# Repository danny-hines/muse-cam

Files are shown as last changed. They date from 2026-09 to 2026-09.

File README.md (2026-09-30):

# Muse Cam

Muse Cam is a physical AI camera that captures a photograph, applies a playful Muse Image preset through Meta Model API, shows the result on the camera, and optionally publishes it to a public web roll.

This repository contains both sides of the project:

- `web/` — Next.js site and device API deployed to Vercel.
- `device-ui/` — touch-first React interface compiled into the Raspberry Pi package.
- `device/` — portable Python client and hardware profiles for Raspberry Pi.
- `hardware/` — physical build plan, working parts list, source CAD, and printable exports.
- `scripts/` — repeatable device installation tooling.
- `docs/` — API and deployment documentation.

## Current status

The web/API foundation is functional:

- Responsive per-event galleries that update live, a full-screen slideshow for event screens, an event-code home page, and individual photo pages.
- Individual, revocable device credentials plus a legacy single-token fallback.
- Event assignment and 30-minute, single-use device setup codes.
- Idempotent capture IDs.
- Generation, status, image download, share, and unshare endpoints.
- Thirty versioned image presets, plus per-event style lists and event-only styles.
- Mock image transformation for end-to-end development without a Meta key.
- Neon Postgres and private/public Vercel Blob adapters.
- A protected operator dashboard for registration, moderation, and deletion.
- Opt-in original-photo publishing with an accessible before/after control.
- Muse Spark captions for shared photos, written after publishing.
- In-memory development fallbacks and included demo frames.

The Raspberry Pi application includes Picamera2 capture, local SQLite queuing, offline retry, diagnostics, systemd startup, and desktop simulation. It has two interchangeable front ends: the proven native framebuffer app for SPI/HAT displays and a local Chromium interface for the 800×480 Waveshare DSI display. The browser never receives the device credential; it talks only to the camera service on localhost.

## Local development

Requirements: Node.js 20.9+ and pnpm 11.

```bash
cp web/.env.example web/.env.local
pnpm install
pnpm dev
```

Set a development `DEVICE_API_TOKEN` in `web/.env.local`. With `MODEL_PROVIDER=mock`, Neon and Blob are optional. Open [http://localhost:3000/demo](http://localhost:3000/demo) for the demo gallery and [http://localhost:3000/api/health](http://localhost:3000/api/health) for configuration status.

Useful commands:

```bash
pnpm typecheck
pnpm lint
pnpm test
pnpm build
pnpm --dir web token:hash
pnpm --dir web admin:credentials
```

## Deploying to Vercel

1. Import this repository into Vercel and select `web` as the project root.
2. Provision Neon Postgres from the Vercel Marketplace and connect it as `DATABASE_URL`.
3. Create two Vercel Blob stores: one **private** and one **public**.
4. Connect their tokens as `PRIVATE_BLOB_READ_WRITE_TOKEN` and `PUBLISHED_BLOB_READ_WRITE_TOKEN`.
5. Run `pnpm --dir web db:migrate` against the connected Neon database.
6. Generate operator credentials with `pnpm --dir web admin:credentials`, then add the two emitted environment variables to Vercel.
7. Keep the existing `DEVICE_API_TOKEN_SHA256` and `DEVICE_ID` during migration. New cameras can use individual credentials created at `/admin`.
8. Add `SITE_URL`. When enabling Muse Image, add `META_API_KEY`; the documented endpoint and `muse-image-1.0` model are built-in defaults. The same key lets `muse-spark-1.3` caption shared photos.
9. Set `MODEL_PROVIDER=mock` for the first deployment smoke test.
10. Switch to `MODEL_PROVIDER=meta` after adding the Meta API key and running a live image-edit smoke test.

Production device mutations intentionally refuse to run until the database, both Blob stores, device authentication, and selected model provider are configured.

## API smoke test from a workstation

Every photo belongs to an event, so first assign the camera to an event at `/admin`. Until then, uploads return a retryable `503` (`camera_unassigned`).

```bash
curl -X POST http://localhost:3000/api/device/generations \
  -H "Authorization: Bearer $MUSECAM_DEVICE_TOKEN" \
  -F "capture_id=test_$(date +%s)" \
  -F "preset_id=alien-visitor" \
  -F "image=@/absolute/path/to/photo.jpg"
```

See [docs/API.md](docs/API.md) for the complete flow.

## Raspberry Pi installation

The public installer supports the current Camera Module 3 / Pi 3B+ / DSI build and the alternate hardware profiles:

```bash
curl -fsSL https://raw.githubusercontent.com/danny-hines/muse-cam/main/scripts/install-device.sh \
  | sudo bash -s -- --profile pi3bplus-cam3-dsi43 --claim YOUR-SETUP-CODE
```

For the PiSugar 3 Plus, also complete [battery setup](docs/POWER.md) and set `MUSECAM_POWER_BACKEND=pisugar3`. Use `pi3bplus-imx415-tft35` for the SPI screen or `zero2-cam3-displayhat` for the Pi Zero 2 W version. See [docs/DEVICE.md](docs/DEVICE.md) for wiring, diagnostics, simulator usage, and hardware bring-up. See [docs/ADMIN.md](docs/ADMIN.md) for registration and moderation.

The [parts list](hardware/BOM.md), [illustrated build guide](hardware/BUILD.md), [GPIO wiring](hardware/WIRING.md), and [six enclosure STL files](hardware/stl/README.md) cover the Camera Module 3 / PiSugar 3 Plus build. The guide follows the September 16, 2026 assembly notes and includes ten [assembly photos](hardware/photos/README.md) plus four [completed-camera views](hardware/BUILD.md#completed-camera); print settings and a few measurements remain pending. The enclosed prototype processes photos over Wi-Fi and has working audio and battery reporting; Camera Module 3 autofocus remains unresolved in the [recorded hardware checks](docs/CAMERAS.md).

## Privacy defaults

- Uploaded source images are normalized and stripped of EXIF before storage.
- Originals and unshared results use a private Blob store.
- A result is copied to the public Blob store only after the share endpoint is called.
- Event galleries never expose the source photograph unless an operator explicitly enables originals for that photo or event.
- Hiding a photo deletes both public copies but retains private media; permanent deletion removes the database record and all stored media.

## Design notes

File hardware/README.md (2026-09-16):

# Build a Muse Cam

Print the six enclosure parts, gather the [parts list](BOM.md), and follow the
[assembly guide](BUILD.md). Keep the [wiring reference](WIRING.md) nearby while
connecting the amplifier and shutter.

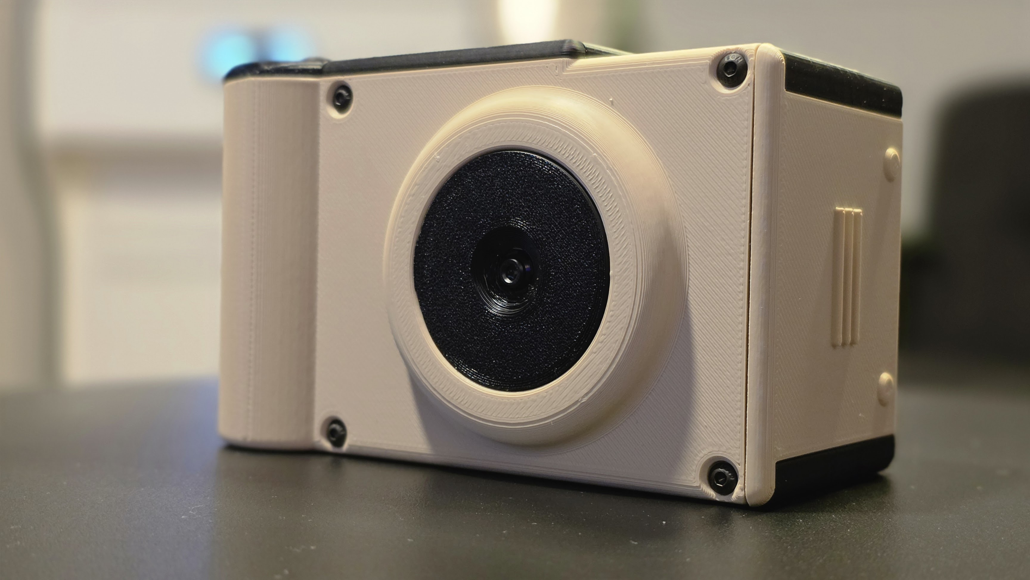
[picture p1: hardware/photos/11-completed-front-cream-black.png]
Completed Muse Cam with cream front and side panels, black housing, and a recessed camera lens


The completed camera. See [front, rear, and open-door views](BUILD.md#completed-camera)
in cream/black and orange/white.

## Current build

The September 16, 2026 instructions cover Danny's enclosure with:

- Raspberry Pi 3 Model B+.
- Raspberry Pi Camera Module 3 Standard.
- Waveshare 4.3-inch 800×480 DSI touchscreen.
- PiSugar 3 Plus and battery.
- MAX98357A I²S amplifier and 3 W speaker kit.
- A 10 mm momentary shutter switch and magnet-retained access doors.

Use software profile `pi3bplus-cam3-dsi43` with
`MUSECAM_POWER_BACKEND=pisugar3`. The shutter connects to physical pins **38 and
39**; physical pin **40** is reserved for amplifier DIN.

## Files

| Resource | Contents |
| --- | --- |
| [Parts list](BOM.md) | Purchase links, quantities, screws, cables, and supplies |
| [Build guide](BUILD.md) | Printing, assembly, software setup, and final checks |
| [Build photos](photos/README.md) | Ten assembly photos and four completed-camera views |
| [Wiring reference](WIRING.md) | Physical pin numbers, BCM GPIO numbers, and audio setup |
| [STL files](stl/README.md) | Six original exports, dimensions, and SHA-256 checksums |
| [Source CAD](cad/README.md) | Location for editable models; source files are still pending |
| [Device setup](../docs/DEVICE.md) | OS installation, diagnostics, and operation |
| [Battery setup](../docs/POWER.md) | PiSugar 3 Plus telemetry and power-manager configuration |

## Build status

An enclosed prototype has processed photos over Wi-Fi, and its amplifier/speaker
has played clean audio. Application sound cues are implemented. Camera Module 3
preview/capture were checked on September 12, and PiSugar 3 Plus battery reporting
on September 13; see [camera results](../docs/CAMERAS.md) and
[power results](../docs/POWER.md).

The guide includes **ten assembly photos and four completed-camera views**
showing the four-magnet layout, door stops, display, Pi/PiSugar stack, lens mount,
speaker placement, and side-door access to USB and Ethernet. The six
supplied STLs are unchanged, with file-integrity and dimension checks. Print
settings, exact screw-head dimensions and M2.5 lengths, cable lengths, and some
connector details still need to be recorded. Camera Module 3 autofocus remains
unresolved in the existing test record, so check lens clearance and near/far
focus before closing the housing.

The assembly guide lists the remaining measurements and checks. Other
software-supported cameras and displays are listed in
[DEVICE.md](../docs/DEVICE.md); their mechanical fit is not established by this
STL set.

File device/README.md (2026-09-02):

# Muse Cam device application

The device package contains the Raspberry Pi camera service, native UI, and production API client. It includes:

- Picamera2 and desktop-simulator camera adapters.
- Direct RGB565 framebuffer and Pimoroni Display HAT Mini outputs.
- Touch, integrated HAT button, GPIO shutter, and long-press power input.
- A responsive Pygame UI for preset selection, capture, processing, review, and sharing.
- A local HTTP/SSE/MJPEG service for the touch-first Chromium UI, with credentials isolated from the browser.
- SQLite persistence and offline retry using idempotent capture IDs.
- PiSugar 2 battery telemetry.
- Hardware diagnostics and systemd startup.

See [`../docs/DEVICE.md`](../docs/DEVICE.md) for installation, wiring, simulation, and hardware bring-up.

The API-only commands remain useful during diagnosis:

```bash
musecam health
musecam presets
musecam claim XXXX-XXXX-XXXX-XXXX
musecam submit /absolute/path/photo.jpg --preset kid-drawing --share
musecam doctor
```

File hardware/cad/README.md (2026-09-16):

# Source CAD

Store editable enclosure and bracket models here. Prefer a format that preserves the
design history; include a neutral STEP export when the authoring tool supports it.

Each CAD release should document:

- Hardware revision and compatible device profile.
- Authoring application and version.
- Units and critical tolerances.
- Purchased-part models used as references and their licenses.
- Mapping from source bodies/components to files in [`../stl/`](../stl/).
- License for the original Muse Cam mechanical design.

Do not commit third-party vendor models unless their license permits redistribution.

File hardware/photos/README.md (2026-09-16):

# Assembly and completed-camera photos

Danny supplied ten assembly photos and four completed-camera photos for this
build guide. They are stored at their original resolution without cropping or
retouching. Numbering preserves the order within each supplied set: 1–10 for
assembly and 11–14 for the completed camera. The [build guide](../BUILD.md)
embeds the assembly photos beside their steps and includes a
[completed-camera gallery](../BUILD.md#completed-camera).

| Photo | Original image | Shows |
| ---: | --- | --- |
| 1 | [Body: top-door magnet](01-body-main-top-magnet.png) | Adhesive at the top-door magnet recess in `body_main` |
| 2 | [Body: side-door magnet](02-body-main-side-magnet.png) | Single body magnet between two door-stop clearances |
| 3 | [Doors: magnets and stops](03-door-magnets-and-stops.png) | One magnet location and two stop screws on each door; side door left, top door right |
| 4 | [Display mounted](04-display-mounted.png) | Display PCB and DSI ribbon in `body_main` |
| 5 | [Pi ribbons and GPIO](05-pi-ribbons-and-gpio.png) | Cables and leads connected with the Pi still accessible |
| 6 | [Pi/PiSugar stack](06-pi-pisugar-stack.png) | Installed stack with battery facing the open front; amplifier alongside |
| 7 | [Camera in lens_back](07-camera-in-lens-back.png) | Camera placement, ribbon exit, and separate `lens_front` |
| 8 | [Lens assembly screws](08-lens-assembly-screws.png) | Two screws joining the lens halves from the rear |
| 9 | [Lens mounted to front](09-lens-mounted-to-front.png) | Rear flange attached to the inside of `body_front` |
| 10 | [Speaker mounted to front](10-speaker-mounted-to-front.png) | Speaker beside the lens mount, cone facing the housing interior |
| 11 | [Completed front, cream/black](11-completed-front-cream-black.png) | Four front-cover screws, lens opening, and closed side door |
| 12 | [Completed rear, cream/black](12-completed-rear-cream-black.png) | Touchscreen surround, closed side door, and wrist strap |
| 13 | [Completed rear, orange](13-completed-rear-orange.png) | Top door, shutter button, wrist strap, and display showing OS boot text |
| 14 | [Side door open](14-completed-side-door-open.png) | Side door slid toward the front, exposing USB/Ethernet ports and the body magnet |

The photos establish the four-magnet layout: two body magnets plus one in each
door. They also show the display PCB marked `4.3inch DSI LCD`, `800×480 Pixels`,
and `2.2`, and a PiSugar battery marked 5000 mAh / 3.7 V / 18.5 Wh.

The completed views show two enclosure color schemes and optional wrist straps.
They document exterior fit and port access; they do not establish focus quality,
battery runtime, or the result of an application capture test.

Use the [wiring table](../WIRING.md#gpio-connections) for pin numbers; not every
GPIO connection or connector contact is visible. Screw lengths come from the
builder's written notes, not measurements inferred from the images. See the
[remaining checks](../BUILD.md#remaining-measurements-and-checks) for information
still needed to reproduce the build fully.

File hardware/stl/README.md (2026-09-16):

# Printable Muse Cam enclosure

Six original binary STL exports supplied by Danny on **2026-09-16**. Print one
of each for the Camera Module 3 / Pi 3B+ / Waveshare DSI / PiSugar 3 Plus build.
The filenames and mesh bytes are unchanged from the supplied files. See the
[parts list](../BOM.md) and [assembly guide](../BUILD.md).

## Scale and dimensions

STL does not store units. **Millimetres are the intended working assumption**
for this enclosure; import at **100% scale** and check these measured bounding
boxes before slicing. Values are X × Y × Z in the original CAD axes, rounded
to three decimals. Rotating a part changes its displayed axis dimensions.
The files retain assembly coordinates and are not laid out on a print bed.

| File | Qty | X × Y × Z (mm, assumed units) | Triangles |
| --- | ---: | --- | ---: |
| [body_front.stl](body_front.stl) | 1 | 129.000 × 10.349 × 79.000 | 7,098 |
| [body_main.stl](body_main.stl) | 1 | 133.000 × 67.656 × 83.000 | 12,338 |
| [door_side.stl](door_side.stl) | 1 | 5.300 × 59.550 × 78.990 | 3,156 |
| [door_top.stl](door_top.stl) | 1 | 64.000 × 47.639 × 5.300 | 3,066 |
| [lens_back.stl](lens_back.stl) | 1 | 55.000 × 6.921 × 55.000 | 3,188 |
| [lens_front.stl](lens_front.stl) | 1 | 44.600 × 6.049 × 44.596 | 1,504 |

## Print preparation

1. Import each file separately or separate the imported objects in your slicer.
   Rotate and place each part on the bed; do not print the assembled arrangement.
2. Check size against the table. `body_main` spans approximately 133 × 67.656 ×
   83 mm in its original axes; a much larger or smaller import has a unit/scale issue.
3. Preview every layer around screw mounts, magnet recesses, and lens locating
   pins. Keep supports removable from those features and cable openings.
4. Remove supports and burrs, then dry-fit doors, lens halves, magnets, and
   purchased parts before gluing or fitting electronics. Do not globally resize
   the enclosure to fix a single tight hole; that changes every mounting location.

## Print settings to record

No slicer profile accompanied these files. Material, orientation, or support
settings below must not be treated as tested until filled in from the actual
print. The export orientation alone is not a printing recommendation.

| Field | Status |
| --- | --- |
| Source CAD / mechanical revision | Editable source and revision name pending; see [CAD notes](../cad/README.md) |
| Printer and process | Pending |
| Material / filament used | Pending |
| Nozzle and layer height | Pending |
| Walls, top/bottom layers, and infill | Pending |
| Orientation for each of the six parts | Pending slicer screenshots |
| Supports, brim, and support interfaces | Pending slicer screenshots |
| Magnet-hole fit and door clearances | Pending printed-part measurements |
| Camera locating-pin and lens-actuator clearance | Pending fit/focus checks |
| Print time and filament quantity | Pending slicer estimates |
| Test print date and final assembled validation | Pending for this documented settings set |

## File integrity

All six files passed binary STL length/triangle-count and finite-coordinate
checks and match their supplied originals. These checks do not establish
manifoldness, slicer compatibility, print quality, or mechanical fit.

Run `shasum -a 256 *.stl` from this directory to compare with:

```text
3075b1e9511f5c1362fa5aead421a088b1111550b8816501f8101e1d849f2379  body_front.stl
7a8fc0d1022d8f4f8952f85d7305699d252f83a94111bdef06fb895fa9331fbe  body_main.stl
97ea211a343902a7f8289fae1af1e4723ec2c2171823ff44b7fcac900dadf849  door_side.stl
5e7b3fde61a35fad9752df0e19703d1eb8fb2210e5cd830ee7748e5cc2bbcd77  door_top.stl
3f474c973b71d8891eedef6b5391fd0790f6d16bde4b0bd29b184232bd79de4a  lens_back.stl
1323c2ce16437ac9b88e231a7ca4db07cb82d0bef665291462da371cb5ea52e2  lens_front.stl
```

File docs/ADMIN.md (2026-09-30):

# Operator dashboard

The private dashboard at `/admin` manages events, camera registration, and public-photo moderation. It is disabled until both admin environment variables are present.

## Configure access

Generate an operator key and a separate cookie-signing secret locally:

```bash
pnpm --dir web admin:credentials
```

Save the plaintext operator key in a password manager. Add only the emitted `ADMIN_KEY_SHA256` and `ADMIN_SESSION_SECRET` values to Vercel, then redeploy. Sessions are signed, `HttpOnly`, `SameSite=Strict`, production-only secure cookies that expire after 12 hours. Authentication is checked again inside every mutation.

This lightweight operator-key flow is appropriate for the showcase build and a small trusted operations team. Before delegating access broadly, replace it with an identity provider that supports individual accounts, MFA, and audit logs.

## Events and original photos

Every photo belongs to an event. Each event has a public gallery at `/<event-slug>` (for example, `/sei-nyc`). Open it with **View gallery** in the dashboard. The gallery shows only that event's shared photos; private photos stay private, and photo pages link back to and navigate within their event. The home page lists no photos: visitors enter an event code there, or a pasted gallery URL, and are taken to that event's gallery. Camera assignments apply to new uploads; older photos keep their saved event.

Events also define the privacy default for original photos. “Allow before-and-after originals” means that photos shared by a camera assigned to that event publish both the transformed image and the normalized source image. It is off by default.

For a photo shared without its original, an operator can later choose **Enable original**. The public detail page then displays explicit Transformed and Original controls. Originals are not revealed on feed hover.

Each event also has an **Automatically share new photos to the event gallery** setting, off by default. Set it when creating an event, or edit it under that event and select **Save settings**. You can also change whether future shares include originals there. Enabling auto-sharing does not publish older photos, and disabling it does not retract existing shares.

The server applies the event's auto-share setting when an upload first arrives. Successful auto-shares return their link with the generated photo, so the camera shows it as shared without a restart. Sharing failures retry the saved result without another model generation.

Deleting a photo in the camera gallery also retracts its public share, including a public original. Private server copies remain available for admin moderation. Offline deletions remove the local photo immediately and persist a share-removal request across camera restarts; the public link remains available until the camera reconnects and that request succeeds. The gallery shows pending share removals. Automatic local-history pruning does not retract public shares.

Deployment requires applying the database migration with `pnpm --dir web db:migrate`, deploying the updated web app, and updating the camera service and bundled device UI for deletion syncing. Deploy the server before updating cameras. Existing events retain manual sharing after migration.

## Event styles

Each event has a **Camera styles** list under its settings. By default an event uses the default catalog, and it picks up new default styles as they are added. Check or uncheck styles and select **Save settings** to give the event its own list. Checking exactly the default catalog returns the event to the default. An event needs at least one style.

**Event-only** styles, such as the Meta event's, never appear in the default catalog. They are available only at events that check them, and the server refuses them from cameras at any other event with a non-retryable `403` (`preset_unavailable`). The camera marks that photo as failed and keeps the original for **Restyle**. Default styles an event has unchecked are still accepted, so a camera with an out-of-date list, or photos queued offline, never fail.

**Who picks the style** chooses between guests and the server. With **Surprise: the server picks for each photo**, cameras list a single **Surprise** style. Cameras updated after September 29 then hide the style picker, and gallery **Restyle** makes a new surprise photo without asking for a style. Older cameras also show their own **Random**, which resolves to Surprise too. Each camera works through the event's whole list in a random order before it repeats a style, then continues with the styles it used longest ago. For each photo, the server tries up to three styles in that order. It moves on to the next one only when Muse Image filters a style for that photo, and it records the style that worked on the photo. Galleries and captions use the real style. Cameras updated after September 29 also label the photo with it; older cameras label it "Surprise". A camera that hasn't restarted still sends the style a guest chose, and the server honors it.

Cameras load their style list when the camera service starts, so **restart the camera after changing an event's styles or who picks them** or moving a camera to an event with different styles. No camera update is needed: cameras have always sent their credential with the style request. A camera that can't reach the server when it starts keeps the last list it loaded.

## Live gallery and slideshow

An event's gallery at `/<event-slug>` updates itself. It checks for new photos every 5 seconds, adds them at the top, and drops photos that were hidden or deleted. **Start slideshow** opens `/<event-slug>/show`, a full-screen view for big screens:

- Each photo from the roll stays up for 8 seconds, newest first, then the roll repeats.
- A new photo is shown next, ahead of the roll, with a **Just now** badge for 10 seconds. If the event publishes originals, the real snapshot shows first ("The real moment") and wipes to the transformed photo after 2.5 seconds.
- Captions fade in when Muse Spark finishes, usually 10–15 seconds after a photo is shared.
- **Hide** or **Delete permanently** in this dashboard removes a photo from every open gallery and slideshow within about 5 seconds.
- A QR code links to the event gallery so guests can find their photo.

On the laptop driving a screen, open the slideshow, then select **Full screen** or press `F`; the browser needs that click or key press. Moving the mouse shows the controls, and they fade after 3 seconds along with the cursor. The right arrow key skips ahead. The page asks the browser to keep the screen awake, but set the laptop not to sleep on power as well. If the network drops, the slideshow keeps cycling the photos it has and catches up when it reconnects.

Only shared photos appear, so turn on auto-sharing for events with a live screen. A photo usually appears 20–40 seconds after the shutter.

## Register a camera

An existing camera configured with `DEVICE_API_TOKEN` or `DEVICE_API_TOKEN_SHA256` appears automatically when an operator opens the dashboard or the camera makes a request. It keeps its `DEVICE_ID` and credential, starts without an event, and supports the same event assignment and revoke controls as cameras registered with a setup code. Assign it an event before use. No reinstall is needed. Syncing or rotating the configured token preserves its event and revoked status.

1. Create or choose an event. Setup codes require one.
2. Enter a suggested camera name, choose the event, and select **Create setup code**.
3. Within 30 minutes, run the displayed command on the camera.
4. Restart `musecam.service` if it is already running.

Each code is one-time and stored only as a hash. Each resulting camera token is unique and stored only as a hash. **Revoke** immediately blocks that camera without affecting other units.

For a fresh public-repository install, pass the code directly to the installer:

```bash
curl -fsSL https://raw.githubusercontent.com/danny-hines/muse-cam/main/scripts/install-device.sh \
  | sudo bash -s -- --profile pi3bplus-imx415-dsi43 --claim XXXX-XXXX-XXXX-XXXX
```

If the installer stops with `Registration failed (500)`, package installation has
succeeded but the registration server failed. Check the server logs for
`/api/device/claim` and resolve that error first. Then generate a fresh setup code
and rerun the original installer command with the same hardware profile and the
new code. The installer reuses the existing checkout and finishes writing the
configuration and installing the services. Running `musecam claim` alone does not
finish an interrupted first installation.

## Rename a camera

In **Cameras**, edit the registered camera's **Name** and select **Save**. The name appears in the dashboard and on public photo cards and pages, including photos taken before the rename. Renaming is server-only: the camera keeps its registration, token, event, and revoked status, and needs no restart. Environment-configured cameras keep their new name when their token syncs or rotates.

## Change a camera's event

In **Cameras**, choose an event from the registered camera's **Event** dropdown and select **Save**. A camera can move between events but cannot be left without one. The camera keeps its registration and token; no restart is needed.

A camera without an event, such as a newly synced environment-configured camera, is marked **Uploads paused** in the dashboard. The server answers its uploads with a retryable `503`, so the camera keeps captures queued; once assigned, they upload to that event.

The change applies to new uploads, including captures waiting to be uploaded. Photos already uploaded keep their original event and follow that event's original-photo privacy setting.

## Captions

When a photo is first shared, Muse Spark writes a short "caption this" style joke about the transformed image. The caption appears on the gallery card, the photo page, and link previews about 10–15 seconds after sharing, without delaying the camera. Muse Spark reads text in the photo, but captions leave out people's names, even from badges or name tags; a pet's name from a collar tag can appear. It needs no camera update and uses the same `META_API_KEY` as Muse Image; with `MODEL_PROVIDER=mock`, captions are placeholders.

Each capture in the dashboard shows its caption. **Write caption** captions a photo that has none, such as one shared before captions existed or one whose caption request failed. **New caption** replaces a caption that didn't land. A photo keeps its caption when it is hidden and shared again.

## Moderation

- **Hide** removes transformed and original public Blob objects and clears the public URL. Private copies remain available to the operator.
- **Delete permanently** removes public and private Blob objects and deletes the database record. The dashboard requires a browser confirmation first.
- **Revoke** disables a camera credential. It does not hide that camera's existing photos.

Rate limits, audit history, and role-based access are intentionally deferred hardening work; the individual device tokens and operator boundary make those additions incremental.

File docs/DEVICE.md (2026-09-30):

# Raspberry Pi bring-up

Muse Cam supports two display paths. The current SPI/HAT builds use the native Python/Pygame interface. The Waveshare DSI build uses a local Chromium interface backed by a Python camera service. In both cases, camera capture, buttons, credentials, persistence, and API calls remain in Python; the DSI browser only connects to `127.0.0.1`.

For the physical parts list, enclosure plan, printable assets, and exact amplifier/shutter pin table, see [the hardware guide](../hardware/README.md) and [wiring reference](../hardware/WIRING.md). This document remains the source of truth for software installation and device bring-up.

## Supported profiles

| Profile | Board | Display/input | Camera | Battery |
| --- | --- | --- | --- | --- |
| `pi3bplus-imx415-tft35` | Pi 3B+ | MPI3501 ILI9486 480×320 framebuffer plus XPT2046 touch | IMX415 fixed focus, 1920×1280 still | PiSugar S Plus; no telemetry |
| `pi3bplus-imx415-dsi43` | Pi 3B+ | Waveshare 4.3-inch 800×480 DSI display plus capacitive touch | IMX415 fixed focus, 1920×1280 still | PiSugar S Plus; no telemetry |
| `pi3bplus-imx519-dsi43` | Pi 3B+ | Same Waveshare DSI display/touch | IMX519 continuous autofocus, 1920×1280 still | PiSugar S Plus; no telemetry |
| `pi3bplus-cam3-dsi43` | Pi 3B+ | Same Waveshare DSI display/touch | Camera Module 3 continuous autofocus, 1920×1280 still | PiSugar S Plus; no telemetry |
| `zero2-cam3-displayhat` | Pi Zero 2 W | Pimoroni Display HAT Mini plus A/B/X/Y buttons | Camera Module 3 continuous autofocus, 2048×1536 still | PiSugar 2 telemetry when its manager is installed |

The battery column shows profile defaults. For the current PiSugar 3 Plus build,
follow [POWER.md](POWER.md) and set `MUSECAM_POWER_BACKEND=pisugar3`; this
overrides the Camera Module 3 profile's PiSugar S Plus default.

The IMX519 DSI profile has passed initial physical focus and capture checks.
Camera Module 3 Standard preview and capture have been checked, but lens movement
and autofocus remain unresolved on the current unit. All cameras use Picamera2.
See [Camera options and swaps](CAMERAS.md)
for driver requirements, Standard/Wide variants, enclosure status, and the procedure
for changing cameras without losing the local gallery.

All profiles reserve BCM GPIO 20 (physical pin 38) for the shutter. Connect the button to ground (for example physical pin 39); the software enables the internal pull-up. The SPI and Zero profiles also use GPIO21 (physical pin 40) for a shutdown button held for 1.5 seconds. The enclosed DSI build uses GPIO21 exclusively for amplifier DIN, so its profiles omit the shutdown-button input. See the audio setup below before enabling I²S.

## Prepare Raspberry Pi OS

Use **Raspberry Pi OS Lite (Legacy, 64-bit)** based on Debian Bookworm, with SSH and Wi-Fi configured in Raspberry Pi Imager. The DSI installer adds the minimal X server and Chromium packages, so the full desktop image is not required. Before installing:

1. Connect the CSI camera with the Pi powered off.
2. For the SPI profile, seat the MPI3501 directly on the GPIO header. For DSI, connect the Waveshare screen to the Pi 3B+ display connector with power disconnected and the contacts oriented for both sockets.
3. Check the camera ribbon orientation at both ends before applying power.
4. Connect the shutter to GPIO20. On the SPI/Zero profiles, an optional shutdown button uses GPIO21; on the enclosed DSI build, GPIO21 belongs to the amp. The MPI3501 uses GPIO17, 24, and 25 in addition to the SPI pins.

## One-command installation

Pi 3B+ with the Waveshare DSI display and IMX415:

```bash
curl -fsSL https://raw.githubusercontent.com/danny-hines/muse-cam/main/scripts/install-device.sh \
  | sudo bash -s -- --profile pi3bplus-imx415-dsi43 --claim YOUR-SETUP-CODE
```

Pi 3B+ with the current SPI display:

```bash
curl -fsSL https://raw.githubusercontent.com/danny-hines/muse-cam/main/scripts/install-device.sh \
  | sudo bash -s -- --profile pi3bplus-imx415-tft35
```

Pi Zero 2 W:

```bash
curl -fsSL https://raw.githubusercontent.com/danny-hines/muse-cam/main/scripts/install-device.sh \
  | sudo bash -s -- --profile zero2-cam3-displayhat
```

For IMX519 or Camera Module 3, substitute the corresponding DSI profile from the
table and follow the [camera-specific setup](CAMERAS.md) first. IMX519 autofocus
requires Arducam's camera packages.

The installer can exchange a 30-minute setup code from `/admin` for an individual device credential. Without `--claim`, it asks for the legacy plaintext token through `/dev/tty`. It creates a locked-down `musecam` system user, installs the selected display and camera configuration, installs the Python package, verifies the API, and enables `musecam.service`. The DSI profiles also install and enable `musecam-kiosk.service` and `musecam-control.service` for local Wi-Fi and software updates. It reboots automatically when a hardware overlay changes. Rerunning performs a fast-forward update and preserves the secret; add `--reconfigure --claim CODE` to replace an existing credential.

The DSI installer follows Waveshare's current 800×480 setup: it enables full KMS and uses the dedicated Waveshare panel overlay when the OS provides it, otherwise the compatible 7-inch DSI overlay. The display is driven at its native refresh rate rather than copying frames over SPI.

## Validate before starting the enclosure

Stop the UI while diagnosing so it does not hold the camera or display:

```bash
sudo systemctl stop musecam
sudo -u musecam /opt/muse-cam/.venv/bin/musecam --config /etc/musecam/device.env doctor
sudo systemctl start musecam
# DSI builds: stopping musecam also stops its dependent touchscreen service.
sudo systemctl start musecam-kiosk
```

The doctor checks the board model, detected sensor against the camera profile,
camera overlay conflicts, focus configuration, display, GPIO, writable local
storage, optional PiSugar service, and the production API. Autofocus availability
is verified when the application opens the camera.

Useful commands:

```bash
systemctl status musecam
journalctl -u musecam -f
# DSI profile only
journalctl -u musecam-kiosk -f
sudo systemctl restart musecam
sudo nano /etc/musecam/device.env
```

The application automatically prefers `/dev/fb1` when HDMI owns `/dev/fb0`, then falls back to `/dev/fb0` when the MPI3501 is the only screen. Override this by adding `MUSECAM_FRAMEBUFFER` to `/etc/musecam/device.env` only when diagnostics show an unusual framebuffer assignment. Touch orientation can be corrected in the selected TOML profile with `touch_swap_xy`, `touch_invert_x`, and `touch_invert_y`.

The SPI Pi 3 profile captures at 15 FPS and renders the newest frame at 6 FPS. Its framebuffer writes only changed scanlines and requests a conservative 20 MHz SPI clock. The DSI profile captures a 15 FPS preview and supplies up to 10 FPS local MJPEG to the 800×480 Chromium UI. Above 75°C, preview delivery slows to at most 5 FPS until the Pi cools to 68°C; still-photo resolution is unchanged. The display itself refreshes at native DSI speed.

The kiosk sets `TMPDIR=/dev/shm` for Chromium. Debian's Chromium adds `--disable-dev-shm-usage` whenever `/dev/shm` has less than 3.8 GB free, which is always true on a Pi. Chromium then keeps shared memory, including every preview frame, in `/tmp` on the SD card. On 2026-09-29 that meant about 38 MB/s of card writes and a 1–2 second preview freeze every few seconds. With RAM-backed `TMPDIR`, card writes drop to near zero. To check a camera, watch the `bo` column of `vmstat 1`; it should stay near zero while the preview runs.

## DSI touchscreen controls (0.3)

The viewfinder fills the 800×480 screen. Press the physical GPIO20 shutter to take a photo; there is no on-screen shutter. Choose a style from the scrollable translucent rail on the right, or hide it for an unobstructed view. **Random**, the first option, chooses an available style separately for each shot. The actual style is saved with the photo, so retries keep that choice. Random is also available when restyling an existing original.

Tap the top-right **Timer** control to cycle **Off → 5s → 10s → Off**. With the timer enabled, the physical shutter starts a visible countdown and a short speaker beep each second before taking one photo. Preview and background processing continue. **Cancel** or Escape stops the countdown; extra shutter presses during it do not queue more shots. The setting persists across restarts, but an unfinished countdown does not. Beeps follow the master volume and mute settings.

The adjacent icons open the local gallery and settings. Pressing the shutter while browsing the gallery or a single photo returns to the camera without taking a photo or starting the timer. Press it again from the camera view to capture. Keyboard testing supports arrows to change style, Space/Enter for the same shutter behavior, and Escape to return to the camera. When a button has keyboard focus, Space/Enter activates that button instead.

On autofocus camera profiles, tap the preview to focus on a subject. Amber
brackets indicate focusing; green means the camera reports focus achieved.
The selected area stays active after a shot. **Auto area** restores default
automatic metering. Style scrolling and gallery gestures do not change focus.
See [tap-to-focus behavior](CAMERAS.md#tap-to-focus-on-the-dsi-touchscreen).

Captures return to the viewfinder as soon as the original is saved. A single background worker processes the queue while you continue shooting. A quiet chirp accompanies processing; a tappable notice opens a completed or failed photo. Network interruptions retain the original and retry with the same capture ID and increasing delays. Newly captured photos take priority over repeated network retries. The queue survives restarts and pauses new captures at 30 pending photos or less than 150 MB free.

The Picamera2 backend keeps the full-size still and a small YUV preview stream
running in one configuration, with no application raw stream. Each shutter press
saves the existing main stream; it does not reallocate camera buffers. On the
Pi 3, switching modes previously exhausted contiguous DMA/CMA memory while
returning to preview, even with ordinary system RAM free. Resolution remains
1920×1280 across the Pi 3 DSI camera profiles. The autofocus profiles keep
continuous focus active; see [CAMERAS.md](CAMERAS.md) for capture settling behavior.

Frame requests time out after three seconds. The browser runtime clears stale
preview state, closes the camera, and tries to reconnect. After three consecutive
startup failures it pauses automatic retries and offers **Restart camera**.
Gallery navigation and background photo processing remain available. A camera is
only marked ready after delivering a frame, and restarting the service reconnects
the browser's preview stream. See the [Picamera2 manual](https://datasheets.raspberrypi.com/camera/picamera2-manual.pdf)
for the main/lores stream and camera-buffer model.

**Your roll** contains every local original and imagined result, with filters for ready, waiting, and failed photos. Hold a result to compare its original; release to return. **Restyle** submits a copy of the original with the chosen style and adds a separate gallery entry. **Retry** creates a new attempt for a failed generation, retaining the failed entry for reference. Photos in this DSI gallery are not automatically pruned. **Share** publishes a completed result to the camera's event gallery only when explicitly tapped.

Swipe left for the next (older) gallery photo and right for the previous (newer)
photo. Navigation follows the selected gallery filter, continues across loaded
pages, and stops at either end. The arrow buttons provide the same navigation.
Pinch a gallery photo to zoom from 1× to 4×, then drag with one finger to pan;
swipes only change photos when zoomed out.
Double-tap to switch between 2× and the full photo, or tap **Fit** to reset.
A stationary hold (or the **Hold** button) compares the original at the same zoom;
moving or adding a second finger cancels comparison. Original-only photos also
support zoom, and opening a different photo resets the view. With the viewer
focused, left/right arrows browse while zoomed out, `+`/`-` adjust zoom, and `0` fits the photo.
Zoom affects only the viewer,
not saved or shared images.

**Settings** includes:

- Sounds: persistent master volume, mute, optional quiet processing chirps, and previews of the shutter click, processing, success, and failure cues. The default is a conservative 35%; zero silences every cue. Original synthesized sounds require no downloaded audio assets.
- Wi-Fi: nearby networks, saved-network reconnection, hidden SSID entry, and a touchscreen password keyboard. A failed join removes its new profile and attempts to restore the previous connection. WPA personal and open networks are supported; enterprise certificates and captive-portal login are not configured here. Use a suitable office guest network or hotspot, or provision an enterprise profile separately.
- Storage: free/used space and photo counts. Originals and every treatment remain on the camera.
- Device: hostname, addresses, installed commit, battery capability, and update controls. PiSugar S Plus does not expose a percentage; the interface reports that limitation.

Open a photo in **Your roll → Delete** to remove that entry, its original, and its
imagined result from the camera. The confirmation defaults to **Keep photo**.
Other restyled versions are preserved; shared copies remain online. Waiting
photos can be deleted to cancel their queued processing. A photo being processed
or shared must finish before deletion becomes available.

Updates fetch `origin/main` and accept only clean, fast-forward releases with prebuilt UI assets. Pending processing/sharing blocks installation. The update worker installs the Python package and control service, verifies the camera starts, and restores the previous commit/package if startup fails. Photos, sound settings, Wi-Fi profiles, and device credentials live outside the release checkout and are preserved. Keep power connected during an update. Local source edits block the release updater rather than being discarded.

This repository is private. The assembled camera uses a dedicated read-only GitHub deploy key under `/root/.ssh/musecam-update`, pinned GitHub host keys, and an SSH origin URL. The private key never leaves the camera. Other cameras need their own read-only repository access before update checks can fetch releases; do not copy an account-wide GitHub token onto a camera.

The browser and camera API bind only to loopback. Mutating API requests require a local Host, matching Origin when supplied, and `X-MuseCam-Request: 1`. A root-owned helper exposes only fixed Wi-Fi/status/update operations on a Unix socket accessible to the `musecam` group. Wi-Fi passwords travel over that socket and NetworkManager D-Bus, never command arguments or application logs. The helper must be running for these settings to work:

```bash
systemctl status musecam-control
journalctl -u musecam-control -f
```

## Native SPI / Display HAT controls

| Action | Touch | Keyboard/simulator | Display HAT Mini | External button |
| --- | --- | --- | --- | --- |
| Previous preset | `PREV` | Left / A | A | — |
| Capture | `SNAP` or preview | Space / Enter | X | GPIO20 |
| Next preset | `NEXT` | Right / D | B | — |
| Share result | `SHARE` | S | Y | — |
| Safe shutdown | — | P | — | Hold GPIO21 for 1.5 seconds |

The native runtime retains its existing synchronous interface and latest-100 finished-photo retention. The enclosed DSI prototype has no separate GPIO shutdown button; GPIO21 belongs exclusively to the amp DIN wire.

## Desktop simulator

The simulator exercises the same UI and state machine without Raspberry Pi modules:

```bash
python3 -m venv .venv
.venv/bin/pip install -e './device[sim,test]'
MUSECAM_DATA_DIR=./data .venv/bin/musecam run --simulate --offline
```

To exercise the 800×480 browser UI instead:

```bash
pnpm --dir device-ui build
MUSECAM_DATA_DIR=./data .venv/bin/musecam serve \
  --profile pi3bplus-imx415-dsi43 --simulate --offline --port 8080
```

Open `http://127.0.0.1:8080`. Arrow keys change presets, Space/Enter captures, and Escape returns to the live view. Gallery, restyling, sound controls, Wi-Fi keyboard, and update checks can be explored without hardware. Simulated results are local test images; sounds play only on the physical camera.

Keyboard controls are shown in the table above. Remove `--offline` and pass `--config /path/to/device.env` to exercise the deployed API with the simulated camera.

## Amplifier and speaker bring-up

The enclosed prototype's I²S amp and speaker passed an initial test on 2026-09-07:
two 48 kHz stereo test tones at 2.5% digital amplitude played as the `musecam` user,
and Danny confirmed clean sound. The module works with the `max98357a,no-sdmode`
overlay. The September 16 parts list identifies the selected module as a
MAX98357A amplifier and 3 W speaker kit; speaker impedance and connector details
are still pending in the [BOM](../hardware/BOM.md). Application
sound cues are now implemented in `device/src/musecam/audio.py` and controlled from Settings → Sounds. After a reboot, the amp was detected,
playback as `musecam` succeeded again, both camera services were active, and GPIO20
remained configured as the shutter input.

The application keeps one 48 kHz stereo PCM stream open and sends digital silence
between cues, including while muted. Opening and closing the I²S device for each
sound caused loud pops on the assembled camera; the amp's
[setup guide](https://learn.adafruit.com/adafruit-max98357-i2s-class-d-mono-amp/raspberry-pi-usage)
also recommends continuous silence to prevent start/stop popping. Cues and volume
changes have short fades. A separate audio process keeps camera initialization
and capture work from starving the playback buffer. If the stream fails, sounds
remain disabled until an application restart, rather than repeatedly reopening
the device. Settings shows
the audio error. A service restart or power cycle still interrupts the stream.

The standard amp signals use GPIO18 for BCLK (physical pin 12), GPIO19 for LRCLK
(pin 35), and GPIO21 for DIN (pin 40). See the
[Adafruit wiring guide](https://learn.adafruit.com/adafruit-max98357-i2s-class-d-mono-amp/raspberry-pi-wiring).
GPIO21 is connected only to amp DIN on this unit. The DSI profile omits
`power_gpio`, so the camera does not claim the audio-data pin as a button input.
Do not connect a shutdown button there. The default Pi 3 I²S pin group also claims
GPIO20 (audio input), even though the amp only needs output. The supplied
[`musecam-i2s-output.dts`](../device/overlays/musecam-i2s-output.dts) overlay selects
only GPIO18, 19, and 21, preserving the shutter on GPIO20. This setup targets the
Pi 3 DSI build; the SPI and Zero profiles have not been adapted for it.

To reproduce the audio setup on a Pi 3 DSI build with this wiring and the updated
profile, install the tools and compile the pin overlay:

```bash
sudo apt-get install -y alsa-utils device-tree-compiler
sudo dtc -@ -I dts -O dtb \
  -o /boot/firmware/overlays/musecam-i2s-output.dtbo \
  /opt/muse-cam/device/overlays/musecam-i2s-output.dts
sudo usermod -aG audio musecam
```

Back up `/boot/firmware/config.txt`, comment out `dtparam=audio=on`, and add these
lines in the `[all]` section, in this order, then reboot:

```ini
dtoverlay=musecam-i2s-output
dtoverlay=max98357a,no-sdmode
```

`no-sdmode` matches the five-wire module, which has no separate SD_MODE control
wire. See the [amp setup guide](https://learn.adafruit.com/adafruit-max98357-i2s-class-d-mono-amp/raspberry-pi-usage).
Use `aplay -l` to confirm `MAX98357A` appears. `pinctrl get 18-21` should show
PCM_CLK, PCM_FS, input, and PCM_DOUT respectively while Muse Cam is running.
Play a deliberately quiet WAV through the named card, avoiding numeric card
indices that can change between boots. Stop Muse Cam first: its continuous stream
owns the playback device. Standalone playback can itself pop when its stream
starts or stops, so use Settings → Sounds for routine cue checks.

```bash
sudo systemctl stop musecam
sudo -u musecam aplay -D plughw:CARD=MAX98357A,DEV=0 /path/to/quiet-test.wav
sudo systemctl start musecam
```

The general device installer grants audio-group access, but these optional audio
overlay steps remain manual. Successful playback commands still require a
listener to confirm that the physical speaker produced clean audio.

## Finding the assembled camera

The current unit advertises `muse-cam-1.local`. Danny reserved `192.168.68.104`
for it on the router; its Wi-Fi MAC is `b8:27:eb:85:9c:47`. The Pi received that
address after reboot on 2026-09-07. Direct IPv4 connections from the Mac initially
timed out while local IPv6 SSH worked. After the Pi pinged the Mac and refreshed
neighbor discovery, IPv4 SSH to the reserved address succeeded. The reservation
depends on that router's setup; no router change was needed during this session.
On macOS, `dns-sd -B _workstation._tcp local.` can find its advertised hostname,
and `dns-sd -G v4v6 muse-cam-1.local` shows its current addresses. Stop either
lookup with Ctrl+C. Use `ssh -6` with the hostname or its current link-local IPv6
address and the Mac interface suffix (for example `%en0`) when IPv4 is unavailable.

The camera UI listens only on `127.0.0.1:8080` on the Pi. Access from a workstation
requires an SSH tunnel; discovering its LAN address does not expose the UI there.

## PiSugar 2 telemetry

The Zero profile reads `get battery` from `/tmp/pisugar-server.sock`. Install PiSugar Power Manager if an on-screen percentage is desired. PiSugar S Plus does not provide equivalent telemetry, so the Pi 3 profiles omit it by default. For PiSugar 3 Plus, follow [POWER.md](POWER.md) and select `MUSECAM_POWER_BACKEND=pisugar3` to enable battery reporting.

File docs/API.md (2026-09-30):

# Device API

All camera routes require the camera's credential, except presets, where it is optional:

```http
Authorization: Bearer <device token>
```

The server stores only SHA-256 token digests. New cameras receive an individual, revocable token; the original environment-configured token remains as a migration fallback. A camera can only read or share its own generations. Capture IDs must be stable across retries because the API uses them as idempotency keys.

## Register a camera

An operator first creates a single-use setup code at `/admin`. It expires after 30 minutes.

```http
POST /api/device/claim
Content-Type: application/json

{"code":"XXXX-XXXX-XXXX-XXXX","name":"Lobby Camera"}
```

The response contains a new plaintext token exactly once. The device CLI stores it in `/etc/musecam/device.env`; the server retains only its digest. Claim codes are also stored only as digests and cannot be reused.

## List presets

```http
GET /api/device/presets
Authorization: Bearer <device token>
```

The credential is optional. A camera assigned to an event that chooses its own styles receives that event's list, with event-only styles first. Any other request, including one without a credential or with an unknown one, receives the default catalog. If the server can't load the camera's event it returns `503`, and the camera keeps its cached list. Responses are `private, no-store`.

When the event has the server pick styles, the list holds one entry, `surprise`. Sending `preset_id=surprise` to the generation endpoint makes the server choose from the event's styles, preferring ones the camera hasn't used recently. It tries up to three when Muse Image filters one, and the response's `presetId` is the style it used.

Prompts are deliberately omitted from this response. The device receives names, versions, descriptions, and display colors. Cameras load the list when the camera service starts.

## Generate a frame

```http
POST /api/device/generations
Content-Type: multipart/form-data
```

Fields:

| Field | Required | Description |
| --- | --- | --- |
| `capture_id` | Yes | 8–128 URL-safe characters, reused for retries. |
| `preset_id` | Yes | ID returned by the presets endpoint, or `surprise` for a server-picked style. |
| `captured_at` | No | ISO-8601 timestamp including an offset. |
| `image` | Yes | JPEG, PNG, or WebP, at most 2.5 MB. |

The server rotates, resizes, converts to JPEG, and strips metadata before persistence or model submission.

Example response:

```json
{
  "id": "4aac41ab-8bc6-4eb6-8238-079fed301378",
  "captureId": "camera01_00042",
  "status": "complete",
  "presetId": "alien-visitor",
  "presetVersion": 1,
  "createdAt": "2026-08-31T20:00:00.000Z",
  "completedAt": "2026-08-31T20:00:08.000Z",
  "sharedAt": null,
  "imageUrl": "https://example.com/api/device/generations/4aac.../image",
  "shareUrl": null,
  "errorCode": null
}
```

Submitting the same `capture_id` again returns the existing job and does not call the model twice.

Every photo belongs to the camera's event. A camera without an event receives `503` with `details.code` set to `camera_unassigned`; the camera keeps the capture queued and retries, and the upload succeeds once an operator assigns an event.

If the camera's event has auto-sharing enabled when the upload first arrives, the completed response includes `shareUrl` and `sharedAt`. The event's originals setting still controls whether the source is public. A temporary auto-share failure returns `503`; retry with the same capture ID to publish the saved result without regenerating. Retried older manual or hidden photos are not automatically published when event settings change.

## Read status

```http
GET /api/device/generations/:id
```

The current implementation completes the model request synchronously, but the status resource makes the device client compatible with a future durable asynchronous worker.

## Download the private result

```http
GET /api/device/generations/:id/image
```

Returns the generated image with private cache headers. Device authentication is required.

## Share

```http
POST /api/device/generations/:id/share
```

Copies the result from private to public Blob storage, assigns an unguessable slug, and returns `shareUrl`. Repeated calls are idempotent. The normalized original is published too only when the photo's event has explicitly enabled originals. After responding, the server asks Muse Spark for a gallery caption; the camera API response does not change.

## Unshare

```http
DELETE /api/device/generations/:id/share
```

Deletes all public copies and removes the frame from its event gallery. Private media is retained until an operator permanently deletes the capture.

## Retract a camera-deleted capture

```http
DELETE /api/device/captures/:captureId/share
```

Returns `{ "retracted": true }` once public copies have been removed. Private copies remain. This operation is idempotent and records the retraction even if the upload has not arrived yet, preventing late uploads or sharing retries from publishing a deleted capture. Subsequent generation or share requests for a retracted capture return `410`. A different camera cannot retract an existing capture it does not own.

The camera durably queues this request before removing the local database entry, including when an interrupted upload never returned a generation ID. Network and server failures keep the request queued with retry backoff.

## Health

```http
GET /api/health
```

Returns selected adapter names and whether production dependencies are ready. It never returns secret values.

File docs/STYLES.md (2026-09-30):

# MuseCam styles

The camera has 18 active styles. Every active style works for new captures and
for **Gallery → Restyle**, which creates a separate entry from a saved original.

| Style | Treatment |
| --- | --- |
| After the End | Peaceful, weathered surroundings reclaimed by nature |
| Fridge Masterpiece | Wobbly crayons and joyful childlike drawings |
| First Contact | A friendly visitor and everyday science-fiction wonder |
| Tiny Clay World | Hand-shaped characters and miniature stop-motion sets |
| Found in 1997 | Direct flash, grain, and late-90s outfits, hair, and gadgets |
| Bedtime Legend | Warm, richly painted storybook illustration |
| Panel One | Comic brush inks, halftone dots, and printed color |
| Anime Cel | Nostalgic cel anime with expressive faces and painted scenery |
| Prime Time | Simple, flat-color animated sitcom characters |
| 3D Toon | Sculpted characters in a cinematic 3D animated feature |
| Title Screen | Detailed pixel illustration with retro title-screen atmosphere |
| Player One | Small playable sprites inside a full 16-bit game scene |
| Insert Disc 2 | Smooth shading, chunky console characters, soft photographic textures, and wider portraits |
| Age of Legends | One coherent fantasy mood chosen to suit each photo |
| Paper Universe | Folded and layered paper dioramas |
| Soft Spot | Stuffed felt puppets and embroidered textile scenery |
| Neon Rain | Cinematic futuristic night lighting and reflected neon |
| Stained in Light | Jewel-colored stained glass with slender lead contours |

## September 29: Event-only styles for Meta's internal event

Events can now choose their own style list in `/admin` (see
[ADMIN.md](ADMIN.md#event-styles)). These six styles are **event-only**. They
are not in the default catalog or the camera's bundled list, and the server
generates them only for cameras at an event that turns them on.

| Style | Treatment |
| --- | --- |
| Headset On | A Quest-style VR headset on every person, and on pets |
| Keynote Fit | Alexandr Wang's Connect 2026 outfit: deer tie-dye tee, hiking pants, camo clogs |
| Muse Mode | Every person becomes a plush Muse in their own clothes, pose, and expression |
| Legs Sold Separately | Legless, floating 2022 metaverse avatars in front of a flat Eiffel Tower |
| Gold Chain Era | Oversized black tees, gold chains, and grown-out curls; pets get a chain collar |
| Hydrofoil Freedom | Tuxedos on electric hydrofoils, with one rider holding a flag |

Keynote Fit and Muse Mode send a reference image after the photo
(`web/src/lib/model/references/`). The Keynote Fit reference is cropped below
the face and the prompt uses it only for clothing.

Drafts were tested on six published originals: a posed group of nine, a close
group of four, a gym mirror selfie, a child, a dog, and a family with a dog.
Changes before adoption:

- **Legs Sold Separately:** the first draft left legs on standing people. The
  prompt now spells out that nothing is below the waist, for everyone.
- **Muse Mode:** early drafts put Muse heads on human bodies in groups, left
  some adults human, added small toy Muses instead, or stretched Muses to human
  proportions. The prompt now puts Muse's pear-shaped body first and scales
  each Muse to roughly the person's size without stretching it, so the framing
  holds and clothes fit the round body like a plush toy's. It names men, women,
  and children and forbids extra figures. A draft that made Muses waist-high
  kept the shape but went back to adding toys beside people.
- **Gold Chain Era:** the first draft put most people in shearling jackets,
  hiding the tee and chain, so outerwear is now left off.
- **Hydrofoil Freedom:** group photos were often filtered. Removing the flag did
  not fix it, so a single flag, held by the center rider, is kept for the joke.
- **Keynote Fit:** the first draft pulled back to show everyone's shoes; it now
  keeps the original framing.

The final prompts were then run once more on all six photos (36 requests) with
production input normalization. No gallery entries or public images were
created. Headset On, Keynote Fit, Muse Mode, and Legs Sold Separately
completed 6 of 6. The body-shape revision of Muse Mode then turned every person
into a round Muse on the close group and the family photo, the two that had
failed before. The large group, which had passed with the previous draft, was
filtered in that run. Gold Chain Era completed 5 of 6.
The close group of four was filtered on every outfit-swap prompt tried, but
passed the other styles. Hydrofoil Freedom completed 2 of 6 in that run, and
about half of its requests were filtered across all drafts, including a dog and a
child that had passed earlier. It is the least reliable of the six.

Events that let the server pick styles fall back to another style when one is
filtered, which covers most of these failures.

## September 28: Found in 1997 v2

Version 1 only changed the photographic treatment, so results often looked like a
modern photo with a flash. **Version 2** keeps the disposable-camera flash, grain,
and color cast, and adds a restrained late-90s makeover: everyday period clothes,
a 1990s version of each person's hair, and modern devices and furnishings swapped
for period equivalents in the same places. It allows at most two added props,
asks for plain tape and disc labels, and keeps buildings and skylines as
photographed. It uses the shared costume preservation instructions, so faces,
ages, poses, and layout stay recognizable.

Before adopting it, current and new prompts were compared on five published
originals: a posed group, a group at a skyline window, a gym mirror selfie, a
child in a living room, and a dog on a couch. None were filtered. A first draft
piled up VHS tapes and electronics and printed real movie titles on tape
spines, which led to the prop limit and label wording.

## September 8 curation

After School is now **Anime Cel**, Big Screen is **3D Toon**, and Pocket Arcade is
**Title Screen**. These are metadata changes: their IDs and version-1 prompts are
unchanged. **Player One** is a separate version-1 preset that pulls back from
close-up portraits to show small full-body gameplay sprites in tiled scenery.

Memory Card keeps its ID and becomes **Insert Disc 2**. After comparing five test
variants, **version 3** adopts the exact **Smooth+Wide** prompt: smooth shading,
chunky silhouettes, blurry photographic textures, and a wider waist-up view for
close-up portraits. Already wider photos keep their framing. Empty spaces remain
unoccupied rather than gaining invented game characters.

**Age of Legends v2** absorbs Elven Dawn and Frost & Crown. Its prompt asks the
model to choose one consistent mood: an elven woodland court, a royal castle,
a dragon-themed palace, or a northern great hall. Costumes, hair, architecture,
and lighting follow that choice. Mood selection is model-driven; repeated
generations can still choose the same mood.

Once Upon a Cel, Cartridge World, Elven Dawn, Frost & Crown, Riso Club, and
Blueprint Universe leave the capture and restyle pickers. Their definitions remain
available for existing gallery labels, shared links, queued requests, and retries
of existing failed photos. Retiring a style does not delete any photos. Restyling
an old photo defaults to an active style; a saved Elven Dawn or Frost & Crown
capture selection moves to Age of Legends.

## Prompt behavior

The five **Disc 2** test entries are retired from the capture and restyle pickers.
Their IDs, names, and version-1 prompts remain available for saved gallery photos,
shared links, and retries. Any saved test-mode capture selection moves to
**Insert Disc 2**. The main style keeps ID `memory-card`, now at version 3; changing
its prompt does not alter existing images. Pulling back from a close-up can invent
unseen clothing and poses. Gallery → Restyle still creates a separate photo.

For retries of the retired **Disc 2 · Reference** mode, the provider sends the
original photo first and a bundled rendering reference second. Its prompt limits
the second image to rendering technique,
preserving the first image's subjects and scene. The reference is the user-supplied
1710×900 game screenshot, normalized with the standard input pipeline to JPEG and
stored as base64 in `web/src/lib/model/references/disc-2.json`. Static import keeps
it inside the server deployment; it is not a public asset or device catalog field.
All active styles send one image. The retired **1996** variant uses text guidance
only.

Animation styles describe visual techniques and original character designs.
Fantasy replaces modern clothing and accessories, adapts hair, and reinterprets
the setting while preserving facial identity, age, expression, and pose. Scenes
use peaceful everyday activity, original costumes, architecture, and heraldry.
Output fidelity varies by input and generation.

Prompts live in `web/src/config/presets.ts`. Provider safeguards and single-attempt
error handling remain in place. Compare future outcomes by both style ID and
prompt version as described in `PRESET_RELIABILITY.md`.

## Validation — September 8, 2026

The original 17-style expansion completed 23 direct Meta requests, including six
refinement renders, using one clothed portrait. That is historical validation of
the earlier catalog, not a reliability measurement for the revised prompts.

For the initial curation, the final prompts produced eight successful direct Meta samples:
Insert Disc 2 v2 on a portrait and empty room; Player One on a portrait and dog; and
Age of Legends on the portrait twice, room, and dog. All eight were visually
reviewed. The two fantasy portraits chose a northern setting, while the room and
dog chose woodland styling. The first fantasy draft had two portrait rejections
and one successful room result; simplifying its costume and setting instructions
preceded the four successful final samples. This small check does not establish
a filtering cause or guarantee future acceptance. An earlier console draft also
added people to an empty room; the final prompt explicitly preserves occupancy,
and its room sample did so.

Direct provider checks used production input normalization and created no camera
or server gallery entries or public images. Local synthetic fixtures exercise the
800×480 capture and restyle flows, including photos made with retired styles.
Regression tests cover shared links for all eleven retired presets, offline picker
filtering, gallery labels, and retrying a failed retired style while preserving its
original. The Python wheel contains and loads both catalogs.

## Keeping the device catalog synchronized

`device/src/musecam/presets.json` bundles active public metadata (ID, version,
name, description, accent). `device/src/musecam/retired-presets.json` preserves
metadata for retired styles. Both are included in the installed Python package.
Update these files when changing metadata; web tests verify parity and ensure
prompts are absent from the public API response.

Event-only styles are never bundled: `presets.json` holds the default catalog
only, and the API sends event-only styles just to cameras whose event turns
them on.

Connected cameras fetch the active server catalog at startup and cache it for
offline use. Local filtering also removes retired styles from older cached lists.
Publish the server update before updating the camera. Stable IDs preserve saved
photos and selections across renames, while changed prompts receive new versions.

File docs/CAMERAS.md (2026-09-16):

# Camera options and swaps

Muse Cam uses one Picamera2 capture backend with explicit hardware profiles.
Camera choice changes sensor setup and focusing; the gallery, styles, physical
shutter, sounds, and photo queue use the same application code.

## Pi 3B+ / Waveshare 4.3-inch DSI builds

| Camera | Installer profile | Focus | Validation status |
| --- | --- | --- | --- |
| Arducam IMX415, B0569 | `pi3bplus-imx415-dsi43` | Fixed lens | Existing enclosed build; autofocus is not requested |
| Arducam 16 MP IMX519 autofocus, B0371 | `pi3bplus-imx519-dsi43` | Continuous AF through Arducam's libcamera stack | Initial physical focus/preview/capture checks passed; see results below |
| Raspberry Pi Camera Module 3, IMX708 | `pi3bplus-cam3-dsi43` | Continuous AF through Raspberry Pi's camera stack | Standard module preview/capture checked; focus movement remains unresolved on this unit |

All three DSI profiles use 1920×1280 stills, a 15 FPS camera stream, up to 10 FPS
preview delivery, and the same GPIO20 shutter / GPIO21 amplifier wiring. The
larger sensors are not captured at their maximum advertised resolution: the
initial configuration preserves the Pi 3's established memory budget and upload
sizes. Sensor mode, framing, focus quality, and repeated capture stability still
need to be checked on each new physical module.

Camera Module 3 Standard and Wide share the `cam3` profile. NoIR variants are also
recognized, but the ordinary IR-filtered versions are the intended choice for
normal color photography. The official module offers 75° diagonal coverage for
Standard and 120° for Wide; these are lens specifications, not a promise about
the application's cropped preview. See Raspberry Pi's
[Camera Module 3 specifications and drawings](https://www.raspberrypi.com/products/camera-module-3/).

The IMX519 profile targets the autofocus B0371, not a manual-focus IMX519 board.
Arducam documents Pi 3B+ support and requires its libcamera packages for
autofocus. Follow its OS-specific
[IMX519 installation guide](https://docs.arducam.com/Raspberry-Pi-Camera/Native-camera/16MP-IMX519/)
before enabling this profile. Muse Cam does not download or execute the vendor's
installer automatically. Having an `imx519.dtbo` file alone does not prove that
autofocus is working. Even advertised `AfMode` controls are insufficient: the
sensor tuning file must load the focus algorithm, and frame metadata should show
the lens scanning and reaching focus.

## Tap to focus on the DSI touchscreen

Autofocus runs continuously by default. With an IMX519 or Camera Module 3,
tap a subject in the live preview to select that area. The brackets are amber
while focusing, green when frame metadata reports focus achieved, and coral
if the scan fails. Gray means focus could not be confirmed; try another area.
The selected area continues to autofocus after captures and gallery visits.
Tap **Auto area** to return to the camera's default metering, or restart the
camera. This selects an area in the frame; it does not track a moving person.
Fixed-focus modules do not show these controls.

The browser converts taps through the live image's centered `object-fit: cover`
crop. Python maps those normalized coordinates into the latest `ScalerCrop`
sensor rectangle and meters a 15% window around the point, clamped at its edges.
`AfMetering=Windows` and `AfWindows` select the area. Continuous AF is briefly
paused and resumed to start a fresh scan, acknowledging `AfPauseState` and
draining the three configured frame buffers after each control change. No
sensor reconfiguration or extra camera instance is involved. If acknowledgement
does not arrive within five seconds, AF is resumed and the target remains
unconfirmed until another tap or **Auto area**.

The local API accepts `POST /api/actions/focus` with normalized `{"x": 0.5,
"y": 0.5}`, or `POST /api/actions/focus_auto` with `{}`, using the same local
request protections as other actions. `/api/state` and SSE expose `focus`
(`supported`, `mode`, `point`, `status`) and `previewSize`. Commands are queued
onto the camera thread; focus state changes are published without streaming
every lens adjustment to the UI.

Physical IMX519 validation on September 9, 2026 confirmed pause/resume
acknowledgement, lens movement, and reported focus at three different target
areas followed by automatic-area reset. The sensor crop was
`(708, 674, 3240, 2160)`. Camera Module 3 uses the same control path; see its
partial bring-up results below before treating autofocus as physically verified.

## First installation

Use the Bookworm-based Raspberry Pi OS setup described in [DEVICE.md](DEVICE.md).
Connect the selected module with all power disconnected, install any required
vendor camera packages, and run the Muse Cam installer with the matching profile:

```bash
# IMX519 autofocus (after the Arducam driver setup):
sudo bash install-device.sh --profile pi3bplus-imx519-dsi43 --claim YOUR-SETUP-CODE

# Or official Camera Module 3, Standard or Wide:
sudo bash install-device.sh --profile pi3bplus-cam3-dsi43 --claim YOUR-SETUP-CODE
```

Obtain `scripts/install-device.sh` from this repository as described in
[DEVICE.md](DEVICE.md). Private deployments require their own repository access.
Camera Module 3 uses the Raspberry Pi OS Picamera2/rpicam packages installed by
Muse Cam. The installer may reboot to activate boot settings.

## Swap an existing camera

1. Let pending processing and sharing finish. Use **Settings → Device → Update**
   to install the release containing the new profiles and installer. A normal
   application update preserves the selected camera and does not edit boot settings.
2. For IMX519, follow the linked Arducam driver instructions for your OS. Stop
   Muse Cam while testing vendor camera commands; only one process may own the
   camera. Follow any vendor reboot requirements before continuing.
3. Run **one** of these on the Pi, choosing the module being fitted:

   ```bash
   sudo bash /opt/muse-cam/scripts/install-device.sh \
     --profile pi3bplus-imx519-dsi43 --no-start

   # Or:
   sudo bash /opt/muse-cam/scripts/install-device.sh \
     --profile pi3bplus-cam3-dsi43 --no-start
   ```

   The installer keeps the existing device credential and photo data, selects
   the profile, and stops the camera service. `--no-start` prevents camera
   startup and automatic reboot while the old module is still attached. Existing
   service enablement is retained. Custom extra settings in `device.env` should
   be saved separately before rerunning the installer, which rewrites that file.
4. Run `sudo systemctl poweroff`, wait for shutdown, and disconnect **all** power,
   including the PiSugar battery supply. Fit the module, its correct ribbon, and
   matching enclosure bracket. The Pi 3 camera connector takes a 15-pin ribbon;
   check the camera-end connector and contact orientation rather than assuming
   the IMX415 cable can be reused. See Raspberry Pi's
   [camera connection instructions](https://www.raspberrypi.com/documentation/accessories/camera.html).
5. Restore power. The previously enabled services should start. If this was a
   fresh installation using `--no-start`, enable them after boot:

   ```bash
   sudo systemctl enable --now musecam musecam-kiosk
   ```

The installer backs up the boot configuration before changing camera selection
to `config.txt.musecam-<timestamp>.bak`. It disables previous IMX415/IMX519/IMX708
directives and writes one selected camera in an `[all]` block, with automatic
detection disabled for the Pi 3 profiles. The Zero 2 profile uses automatic
detection. Same-camera reinstalls preserve existing camera overlay parameters,
including rotation; a different module begins with its own default orientation.
Existing KMS memory parameters and amplifier overlays are retained. Custom camera
directives in included boot files or overlays outside these three sensor families
need separate review.

To return to the IMX415, repeat the swap steps with
`--profile pi3bplus-imx415-dsi43`. A vendor camera-stack installation is separate
from Muse Cam's profile selection; changing the profile does not uninstall it.

## Validate each physical module

With the selected camera installed and the Pi rebooted:

```bash
sudo systemctl stop musecam
sudo -u musecam /opt/muse-cam/.venv/bin/musecam \
  --config /etc/musecam/device.env doctor
sudo systemctl start musecam musecam-kiosk
journalctl -u musecam -b -n 80 --no-pager
```

Doctor checks the detected sensor against the profile and flags conflicting
camera overlays. Camera Module 3's `imx708`, `imx708_wide`, `imx708_noir`, and
`imx708_wide_noir` names are accepted by the same profile; these variants are
registered separately in Raspberry Pi's
[libcamera implementation](https://github.com/raspberrypi/libcamera/blob/main/src/ipa/rpi/cam_helper/cam_helper_imx708.cpp).
Application startup verifies that autofocus controls exist and logs the sensor,
capture size, and requested `autofocus=continuous` (or `off` for IMX415). Also check
for driver warnings: `Could not set AF_MODE - no AF algorithm` means that preview
can work while autofocus does not. Install the matching Arducam camera libraries
and verify focus metadata before declaring autofocus operational.

### IMX519 initial hardware results — 2026-09-09

The enclosed Pi 3B+ detected the replacement after changing both the boot overlay
and Muse Cam profile from IMX415 to IMX519 and rebooting. The original Raspberry Pi
camera libraries produced live video but lacked `rpi.af` in the IMX519 tuning file.
Installing Arducam's `libcamera0.5` and `libcamera-ipa`, both version
`0.5.2+rpt20250909-1` for arm64, enabled autofocus. The existing
`python3-libcamera` (`0.5.2+rpt20250903-1~bpo12+1`) and Picamera2 (`0.3.31-1`)
worked with those runtime libraries; no application or kernel replacement was
needed. This was Bookworm 64-bit with kernel `6.12.93+rpt-rpi-v8`.

Frame metadata reported scanning followed by focus lock (`AfState` 1 → 2), with
changing lens positions. Ten consecutive 1920×1280 JPEG captures each returned
an 800×480 preview without allocation errors. The app then served changing live
frames with the gallery, style selection, and volume preserved; audio remained
available. The test originals were kept in a separate local diagnostics folder,
without submitting generation requests or adding gallery entries. Near/far
handheld use and the complete enclosure fit still need user testing.

### Camera Module 3 initial hardware results — 2026-09-12

The Standard module reports `imx708`, a 4608×2592 pixel array, and the expected
180° sensor mounting rotation. Selecting `dtoverlay=imx708` and
`pi3bplus-cam3-dsi43`, then rebooting, restored preview and capture. The chosen
sensor mode is 2304×1296, with a `(360, 0, 3888, 2592)` scaler crop. Ten successive
1920×1280 JPEG captures returned to 800×480 preview without capture errors.

Autofocus is **not yet verified on this physical unit**. It reports `Failed`
and produces a blurred image. Replacing the Arducam `libcamera0.5` and
`libcamera-ipa` packages with Raspberry Pi's matching Bookworm packages
(`0.5.2+rpt20250903-1~bpo12+1`, runtime `v0.5.2+99-bfd68f78`) did not resolve it.
The sensor and `dw9817-vcm` lens controller are both bound to kernel drivers.
Six further captures at manually commanded 0, 1, 2, 4, 8, and 12 dioptres all
showed essentially unchanged sharpness despite changing reported lens positions.
This suggests a blocked or non-moving lens mechanism, but does not establish
the physical cause. Check lens/enclosure clearance and any protective cover
before assuming a software autofocus problem or defective module.

The device now uses the Raspberry Pi camera libraries. Both library sets and
the prior configuration are saved under
`/var/backups/musecam-cam3-swap-20260912T082403Z/`; the IMX519 still requires its
Arducam autofocus stack when switching back. Diagnostic photos are separate
from the gallery in `/var/lib/musecam/diagnostics/cam3-20260912/`. The 69 gallery
entries, selected style, volume, device credential, and display/audio setup
were preserved. Camera, kiosk, and control services remain running.

Before marking a module physically validated, check:

- Live preview and saved originals have the intended orientation and framing.
- A nearby textured object and a distant scene both settle into focus; inspect
  the original using gallery zoom, not only the generated treatment.
- At least ten captures, including several close together and while previous
  photos process, return to live view without allocation errors or a freeze.
- Gallery originals/results, physical shutter, speaker cues, and a power cycle
  continue working. Record the module, OS, camera package versions, and lens variant.

## Focusing and failure behavior

Autofocus profiles request Picamera2's continuous mode. At capture time, Muse Cam
releases frames while the driver reports scanning, allowing up to 1.2 seconds
for settling with a healthy frame stream. If scanning continues, it saves the
latest frame. A failed or unavailable focus-state report also allows capture;
focus lock is not guaranteed. Individual frame requests retain the existing
three-second device timeout and camera recovery behavior. Still and preview
streams stay allocated throughout; capture does not switch sensor modes.
These controls and metadata are described in the
[Picamera2 manual](https://datasheets.raspberrypi.com/camera/picamera2-manual.pdf).

If startup reports the wrong sensor, select the matching profile and reboot.
If it reports missing autofocus controls on IMX519, verify Arducam's libcamera
installation and that the board is the autofocus model. Do not work around the
error by silently disabling autofocus on a build advertised as autofocus-capable.
Standalone `rpicam-hello`/Picamera2 tests must run with Muse Cam stopped.

## Profiles and printable parts

Profile TOML files live in `device/profiles/`. `camera_model` guards against a
wrong sensor; `camera_autofocus` requests continuous focus. Omitting both keeps
the earlier fixed-focus backend behavior for custom profiles. The installer
accepts the five profiles listed in [DEVICE.md](DEVICE.md); new board/display
combinations need their own profile, installer handling, and hardware validation.

The six enclosure STLs supplied on September 16, 2026 are now in
[`hardware/stl/`](../hardware/stl/README.md), with a [parts list](../hardware/BOM.md),
[build guide](../hardware/BUILD.md), and [wiring reference](../hardware/WIRING.md)
for Camera Module 3 / Pi 3B+ / DSI / PiSugar 3 Plus. The guide includes ten
[assembly photos](../hardware/photos/README.md), including camera placement and
the lens mount. Print settings are pending; the photos do not resolve the
autofocus issue recorded above. Check the lens actuator clearance in `lens_back`/`lens_front`
and near/far focus before closing the housing. The separate IMX519 enclosure
revision has not been supplied; do not assume these mounts fit it.

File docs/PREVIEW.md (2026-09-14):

# Touchscreen preview performance

MuseCam keeps still and preview streams allocated together to avoid camera
buffer allocation failures after a photo. The browser receives the low-resolution
stream as MJPEG; still captures retain their separate resolution and JPEG quality.

## Camera Module 3 on Pi 3B+

The DSI 4.3-inch profile uses a 30 fps sensor stream and targets a 15 fps, 800×480
browser preview. Each frame is JPEG-encoded once by Picamera2's YUV-aware encoder.
The controller passes those bytes directly to the browser and includes capture
and encoding time in its frame interval. Still images remain 1920×1280 at JPEG
quality 90. A 30 fps sensor cadence limits exposure to about 1/30 second; dim
scenes may require more gain than the previous 15 fps configuration.

Legacy screen backends can still request a PIL image. Other camera profiles keep
their existing sensor and preview rates until verified on their hardware.

## Kiosk rendering

The original X11 kiosk session had no window manager. Chromium's `--kiosk` flag
alone created a 780×460 window at (10, 10) on the 800×480 display, which prevented
direct full-screen page flipping. Explicit window geometry still produced a
799×479 window because Chromium clamps normal windows below the display size.
The launcher now starts Matchbox, a lightweight embedded window manager, to honor
the browser's fullscreen request. It also passes an explicit window position and
uses the display dimensions reported by `xrandr`.

The device installer includes `matchbox-window-manager` and `x11-utils`. On older
installs that update only the Python package and repository, install these once:

```sh
sudo apt-get install -y matchbox-window-manager x11-utils
sudo systemctl restart musecam-kiosk
```

The launcher retains its previous behavior if the window manager is unavailable,
so missing packages do not prevent the camera from starting.

Chromium also defaults to GPU rasterization on Raspberry Pi OS. In this build,
that used roughly 140–165 MB of VC4 graphics buffers and repeatedly failed to
allocate contiguous memory. Chromium then disabled its GL renderer. The launcher
disables GPU **rasterization** while retaining GPU **composition**, and limits
Chromium's compositor resource budget to 64 MB. This is not a total process or
system GPU-memory limit. A 64 MB compositor budget alone did not stop the failures.

With software rasterization, active V3D allocations fell to roughly 16–18 MB.
Once the window covered the display, the DRM scanout framebuffer IDs alternated
between complete frames instead of remaining fixed during preview updates.

## Measurements (2026-09-13)

On Danny's Pi 3B+ with Camera Module 3, PiSugar 3 Plus, and Waveshare 4.3-inch DSI:

- Before: MJPEG delivery **5.02 fps**, median interval **200 ms**.
- After the camera changes: **14.80 fps**, median interval **66.7 ms**.
- Final kiosk run after restart: **13.79 fps**, median interval **67.1 ms**,
  450 valid preview frames, hardware composition active, and alternating scanout
  framebuffers. The gallery increased by two photos during the verification.
- Standalone sensor-to-JPEG latency: median **77 ms → 49 ms**. This excludes
  browser decoding and display scanout; it is not a measured glass-to-glass delay.
- Still capture and preview resumption passed with both configurations.
- No camera mode switches or extra camera buffers were introduced.

The Pi reported its soft temperature limit active and reached 72°C during final
verification. Thermal protection remains enabled; enclosure cooling can still
affect sustained performance. The application's existing protection reduces the
preview rate at 75°C and restores it after cooling to 68°C.

Device backups: `/var/backups/musecam-preview-20260913/`.
Standalone diagnostic images and measurements:
`/var/lib/musecam/diagnostics/preview-20260913/`.

To investigate regressions, compare delivered MJPEG frame intervals, Chromium's
GPU process arguments (a fallback includes `--use-gl=disabled`), kernel GEM DMA
allocation errors, `/sys/kernel/debug/dri/0/bo_stats`, and the kiosk's actual
geometry via `xwininfo`. Check that scanout framebuffer IDs change while the
preview is active, rather than assuming `--kiosk` made the window full-screen.

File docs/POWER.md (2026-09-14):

# Battery reporting

MuseCam reads battery percentage from PiSugar Power Manager's local Unix socket
at `/tmp/pisugar-server.sock`. PiSugar 2 and PiSugar 3 (including their Plus
models) support this. PiSugar S / S Plus cannot report battery data.

## PiSugar 3 Plus setup

1. With both boards powered off, mount the PiSugar beneath the Raspberry Pi so
   its spring contacts seat against the underside of the GPIO header. The normal
   mounting connection carries both power and I²C; no separate telemetry cable
   is needed.
2. Enable I²C using `sudo raspi-config nonint do_i2c 0`. Verify the board responds
   on bus 1 at its default addresses `0x57` and `0x68`. Poor spring contact can
   prevent communication even when the Pi receives power.
3. Follow [PiSugar's official software instructions](https://docs.pisugar.com/docs/product-wiki/battery/pisugar-power-manager).
   Select **PiSugar 3** for both the server and poweroff package, including when
   installing a PiSugar **3 Plus**. Enable the Unix socket. MuseCam does not need
   the separate PiSugar HTTP, WebSocket, or TCP listeners.
4. Add this setting to `/etc/musecam/device.env`:

   ```dotenv
   MUSECAM_POWER_BACKEND=pisugar3
   ```

5. Restart both camera services:

   ```sh
   sudo systemctl restart musecam.service musecam-kiosk.service
   ```

The percentage appears in the camera header and Settings and refreshes every
five seconds. If the sensor or manager is unavailable, MuseCam shows no
percentage rather than a fabricated reading. Battery percentage is an estimate,
not a precise remaining-runtime measurement.

The power selection is independent of `MUSECAM_PROFILE`, so changing between
IMX415, IMX519, and Camera Module 3 profiles preserves battery support. The device
installer also preserves this setting. Other accepted values are `pisugar2`,
`pisugar-s-plus`, and `none`; the last two disable telemetry. Omitting the setting
uses the camera profile's original power defaults.

Low-battery automatic shutdown and hardware button behavior are separate PiSugar
Power Manager settings. Enabling MuseCam's percentage display does not configure
those policies.

## Verified build

On 2026-09-13, Danny's Pi 3B+ / Camera Module 3 / DSI 4.3-inch build detected a
PiSugar 3 Plus at both default I²C addresses. PiSugar Power Manager 2.3.4-1 was
installed with the PiSugar 3 model and only its Unix socket enabled. MuseCam's
unprivileged service account successfully read a battery level of approximately
61%. The previous boot and device configuration are backed up on the Pi in
`/var/backups/musecam-pisugar3-20260913/`.

Hardware reference: [PiSugar 3 mounting and specifications](https://docs.pisugar.com/docs/product-wiki/battery/pisugar3/pisugar-3-series).

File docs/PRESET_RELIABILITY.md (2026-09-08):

# Preset reliability

## Investigation: September 8, 2026

The server's persisted generation records showed the following outcomes before
the prompt changes. These include earlier testing and are observational counts
of generation records, not a controlled measurement of failure probabilities.
Camera gallery deletions do not remove these server records.

| Style | Prompt version | Complete | Content filtered | Other failures |
| --- | --- | ---: | ---: | ---: |
| After the End | 1 | 0 | 0 | 2 |
| After the End | 2 | 5 | 9 | 0 |
| First Contact | 1 | 3 | 6 | 0 |
| Tiny Clay World | 1 | 7 | 0 | 0 |
| Found in 1997 | 1 | 3 | 0 | 0 |
| Fridge Masterpiece | 1 | 10 | 0 | 0 |
| Bedtime Legend | 1 | 7 | 0 | 0 |

Recent production logs confirm Meta HTTP 400 responses stating that the response
was filtered due to the prompt triggering its content management policy. MuseCam
classifies this as `content_filtered` and returns HTTP 422. Meta's message does
not identify a policy category or reliably distinguish input, prompt, and output
filtering. There is no evidence here for a specific violence, nudity, or other
category. Two early failures predate this classification and remain unknown.

## Prompt changes

- **After the End v3:** specify peaceful, weathered surroundings reclaimed by
  nature, with calm, healthy subjects and clothing preserved.
- **First Contact v2:** specify a friendly background companion and welcoming
  science-fiction details, keeping existing people and animals separate and intact.
- Keep the four successful styles' prompts and versions unchanged.
- Keep provider filtering and single-attempt behavior unchanged. No hidden
  fallback style or automatic retry of rejected generations is introduced.

The shared preservation instruction still preserves identity, pose, composition,
and scene geometry. Style IDs remain stable so existing galleries and the device
continue to work. New generations record the new prompt version. Failure logs now
include preset ID, preset version, and classified error code alongside the photo ID.

## Live spot check

Ten direct Meta requests used the production provider implementation and input
normalization with three previously rejected originals: an empty room, a dog on
a couch, and a clothed portrait. They created no camera or server gallery entries
and did not publish the images. Successful outputs were visually inspected.

| Style | Prompt version | Complete | Filtered | Inputs |
| --- | --- | ---: | ---: | --- |
| After the End | 2, previous | 2 | 0 | Room, portrait |
| After the End | 3, revised | 3 | 1 | Room twice, dog, portrait |
| First Contact | 1, previous | 0 | 1 | Dog |
| First Contact | 2, revised | 3 | 0 | Room, dog, portrait |

First Contact's result is encouraging but too small to establish a reliable rate.
For After the End, the revised prompt rejected the room once and accepted it on a
second request; the previous prompt also accepted it during this check despite
earlier rejection. Its measured improvement is therefore **not established**.
The v3 change is a clearer expression of the intended peaceful aesthetic, not a
guaranteed filtering fix. No individual word or policy category was isolated as
the cause. Further evidence should come from ordinary captures grouped by version.

## Comparing future outcomes

Group by both preset ID and version; combining old and new prompts hides whether
the change helped. The database read below does not retrieve images or credentials.

```sql
SELECT preset_id, preset_version, status, error_code, COUNT(*) AS captures
FROM photos
GROUP BY preset_id, preset_version, status, error_code
ORDER BY preset_id, preset_version, status, error_code;
```

Retry from the camera gallery creates a new capture using the currently deployed
prompt. Sending the old capture ID again returns its existing result by design.

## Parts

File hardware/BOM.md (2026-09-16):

# Muse Cam parts list

Quantities are for **one camera** using the six September 16, 2026 STL exports.
Purchased parts and fastener counts follow Danny's build notes and
[assembly photos](photos/README.md). Supplier links identify the selected items;
pack sizes may exceed the quantities needed.

## Electronics

| Qty | Part | Selected item / notes |
| ---: | --- | --- |
| 1 | Raspberry Pi 3 Model B+ | [Raspberry Pi product page](https://www.raspberrypi.com/products/raspberry-pi-3-model-b-plus/) |
| 1 | Raspberry Pi Camera Module 3 | Standard, ordinary color version used by the current prototype; [selected camera](https://www.amazon.com/dp/B0BRY6MVXL). Check the variant before substituting a Wide or NoIR module. |
| 1 | PiSugar 3 Plus with battery | [Selected power board](https://www.amazon.com/dp/B0H51CW3Q5). [Photo 6](photos/06-pi-pisugar-stack.png) shows a battery marked 5000 mAh / 3.7 V / 18.5 Wh. Manufacturer lists 5 V / 3 A maximum output for the Plus. [Specifications](https://docs.pisugar.com/docs/product-wiki/battery/pisugar3/pisugar-3-series). |
| 1 | Waveshare 4.3-inch DSI touchscreen | 800×480 IPS capacitive touch; [selected display](https://www.amazon.com/dp/B0972Z6VPN), [manufacturer's 4.3inch DSI LCD](https://www.waveshare.com/product/raspberry-pi/4.3inch-dsi-lcd.htm). [Photo 4](photos/04-display-mounted.png) shows PCB revision `2.2`. |
| 1 kit | MAX98357A I²S amplifier and 3 W speaker | [Selected kit](https://www.amazon.com/dp/B0FSZQRWSF); one amplifier and one speaker. Record actual speaker impedance and size from its label before buying a substitute. |
| 1 | 10 mm momentary switch | Normally-open, non-latching; [selected prewired switch](https://www.amazon.com/dp/B0FSZ32QMX). Retain its threaded mounting nut. |
| 1 | microSD card | For Raspberry Pi OS and the local photo gallery; prototype capacity not yet recorded. |
| 1 | USB charging supply and cable | Regulated 5 V supply, up to 3 A to match PiSugar input, with a compatible USB-C charging cable. [PiSugar input specifications](https://docs.pisugar.com/docs/product-wiki/battery/pisugar3/pisugar-3-series). |

## Printed parts

Print **one of each**, six parts total. See the [STL manifest](stl/README.md)
for dimensions and print preparation.

| Qty | File | Purpose |
| ---: | --- | --- |
| 1 | [body_main.stl](stl/body_main.stl) | Main housing; supports display, amplifier, shutter, and Pi/PiSugar stack |
| 1 | [body_front.stl](stl/body_front.stl) | Front cover; holds lens assembly and speaker |
| 1 | [door_side.stl](stl/door_side.stl) | Side access door |
| 1 | [door_top.stl](stl/door_top.stl) | Top access door |
| 1 | [lens_back.stl](stl/lens_back.stl) | Camera support and rear lens-mount flange |
| 1 | [lens_front.stl](stl/lens_front.stl) | Front half of camera sandwich |

## Fasteners and magnets

`M3×6` means an M3 thread with a nominal 6 mm screw length. Head style matters,
especially for the door stops: [photo 3](photos/03-door-magnets-and-stops.png)
shows round heads exposed on the inside of each door. Exact head dimensions,
thread form, and installed protrusion still need measurement. Tighten by hand
and check clearance before substituting screws.

| Qty | Part | Where it goes | Supplied with |
| ---: | --- | --- | --- |
| 4 | M3×4 screws | Two per door, acting as stops behind the front cover | Separate hardware |
| 9 | M3×6 screws | One amplifier mount + four lens assembly mounts + four front-cover screws | Separate hardware |
| 2 | M3×8 screws | Join `lens_back` and `lens_front` | Separate hardware |
| 4 | M2.5 display screws | Attach display to `body_main` | Display kit, per builder; exact length pending |
| 4 | M2.5 Pi/PiSugar screws | Through PiSugar and Pi mounting holes into `body_main` | PiSugar kit, per builder; exact length pending |
| 1 | Switch mounting nut | Secures shutter from inside housing | Switch |
| 4 | 8 mm diameter × 2 mm thick round magnets | Two in `body_main`, one in `door_side`, one in `door_top` | [Selected magnets](https://www.amazon.com/dp/B0CDH2HCV9) |

**Screw total: 23** — 15 M3 screws purchased separately, plus 8 supplied M2.5
screws. No heat-set inserts are specified in the supplied assembly notes.

The [body and door photos](BUILD.md#1-print-and-prepare-the-enclosure) show two
magnet pairs, **four magnets total**. Match each door magnet's polarity to its
body magnet before applying adhesive.

## Cables and assembly supplies

| Qty | Item | Notes |
| ---: | --- | --- |
| 1 | Camera ribbon | Camera Module 3 to Pi 3B+ CSI; use the camera's standard 15-pin cable. Final routed length pending. [Connection reference](https://www.raspberrypi.com/documentation/accessories/camera.html). |
| 1 | Display ribbon | Use the display's included FFC for the Pi 3B+ 15-pin DSI connector. Final routed length pending. [Connection reference](https://www.waveshare.com/wiki/4.3inch_DSI_LCD). |
| 5 conductors | Amplifier-to-Pi wiring | VIN, GND, BCLK, LRC/LRCLK, DIN; insulated female connections to Pi header. Match actual amplifier connector/pad labels. |
| 2 conductors | Shutter-to-Pi wiring | Extend/terminate supplied switch leads as needed, with insulated female connections to pins 38 and 39. |
| 1 pair | Speaker leads | Use the kit's speaker connection if supplied; connects only to amplifier speaker outputs. |
| As needed | Medium-viscosity CA glue | Medium cyanoacrylate glue is shown in photos 1–2. Use adhesive compatible with the printed plastic and plated magnets. |
| As needed | Double-sided mounting tape | Attaches speaker's flat back to inside of `body_front`, with cone facing the housing interior; see [photo 10](photos/10-speaker-mounted-to-front.png). Keep diaphragm clear. |
| As needed | Insulation and strain relief | Heat-shrink for splices, insulating tape, and small cable ties or suitable anchors as routing requires. |
| As needed | Printer filament | Material and quantity depend on confirmed slicer settings; see [print notes](stl/README.md). |
| 1, optional | Camera wrist strap with cord loop | Shown in [completed-camera photos](BUILD.md#completed-camera); exact strap and attachment hardware are not specified. |

Tools: 3D printer and slicer, drivers matching the screw heads, a small wrench
for the switch nut, flush cutters, a deburring tool or fine file, calipers, and a
multimeter for switch continuity. A soldering iron is needed only if the supplied
leads/connectors require soldered terminations.

## Other configurations

The repo also supports IMX415 and IMX519 DSI profiles, an IMX415/SPI display
profile, and a Pi Zero 2 W/Display HAT Mini profile. Their camera mounts, display
fit, power parts, and wiring may differ; see [supported profiles](../docs/DEVICE.md#supported-profiles)
and [camera options](../docs/CAMERAS.md). This shopping list and STL set describe
the Camera Module 3 / Pi 3B+ / DSI build only.

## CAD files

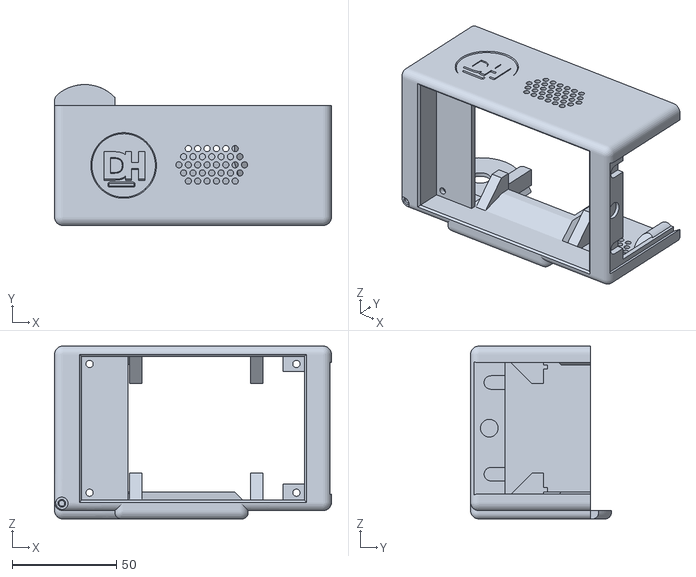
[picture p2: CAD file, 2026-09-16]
hardware/stl/body_main.stl
133.0 x 67.7 x 83.0

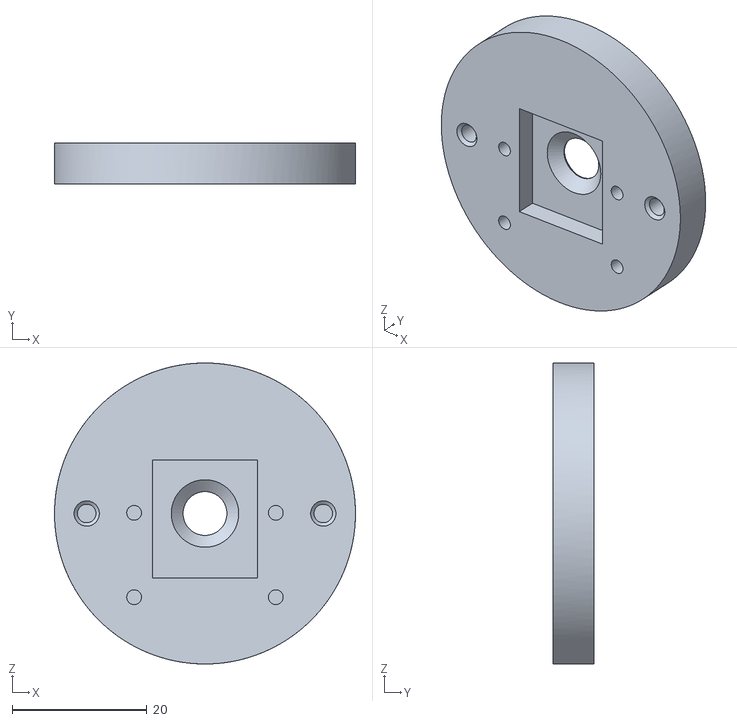
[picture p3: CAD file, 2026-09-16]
hardware/stl/lens_front.stl
44.6 x 6.05 x 44.6

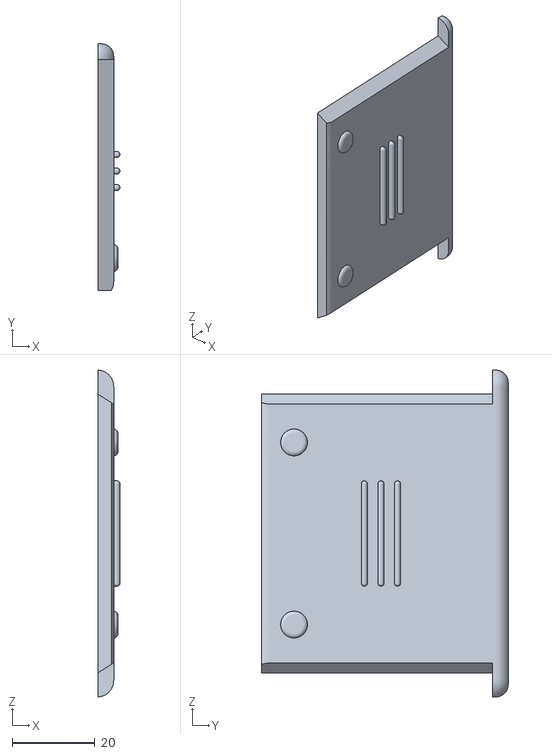
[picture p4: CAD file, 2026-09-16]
hardware/stl/door_side.stl
5.30 x 59.5 x 79.0

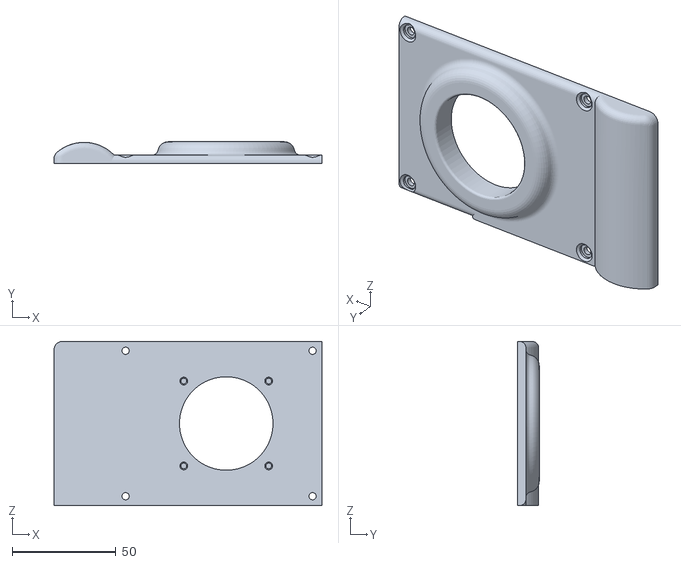
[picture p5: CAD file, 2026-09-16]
hardware/stl/body_front.stl
129.0 x 10.3 x 79.0

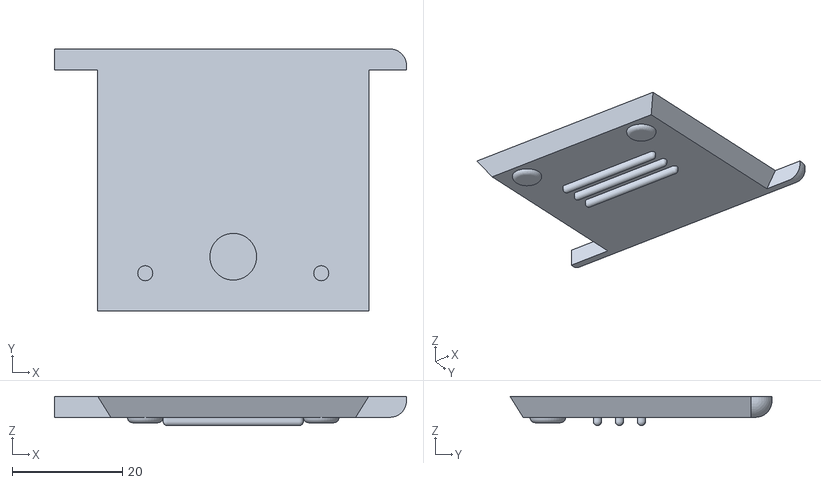
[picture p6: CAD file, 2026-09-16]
hardware/stl/door_top.stl
64.0 x 47.6 x 5.30

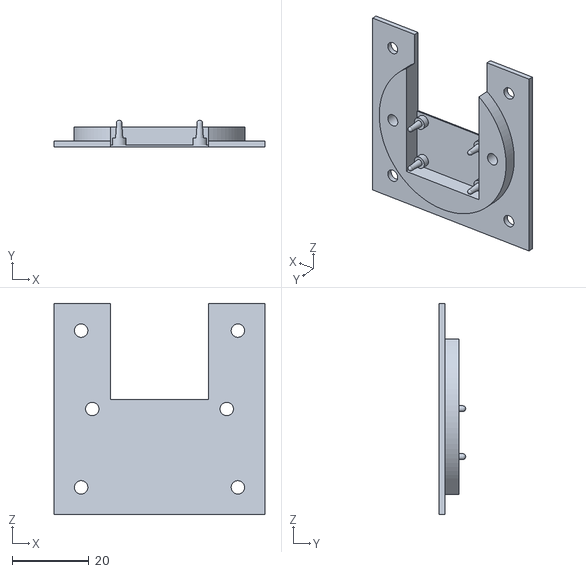
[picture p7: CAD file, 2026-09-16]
hardware/stl/lens_back.stl
55.0 x 6.92 x 55.0

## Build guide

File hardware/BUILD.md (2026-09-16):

# Muse Cam build guide

This illustrated guide follows Danny's September 16, 2026 notes, ten assembly
photos, and four completed-camera views for the Raspberry Pi 3B+, Camera Module 3,
Waveshare 4.3-inch DSI screen, and PiSugar 3 Plus. Gather the [parts list](BOM.md) and keep the
[wiring table](WIRING.md) open. Photos appear beside the matching steps; the
[photo index](photos/README.md) links to the originals. Remaining measurements
and print settings are listed at the end.

## 1. Print and prepare the enclosure

1. Print one of every [STL](stl/README.md): `body_main`, `body_front`, `door_side`,
   `door_top`, `lens_back`, and `lens_front`. Import at 100% using millimetres,
   check the manifest dimensions, and orient each part in the slicer. CAD
   positions are preserved in these exports; they are not print orientations.
   Verified slicer settings are still pending.
2. Remove supports and burrs from magnet recesses, door edges, mounting holes,
   and camera locating pins. Dry-fit the doors, front cover, and empty lens
   halves. Do not force tight printed pins through the camera PCB.
3. Install **four 8×2 mm magnets total**: two in `body_main` (one at each door
   opening), one in `door_side`, and one in `door_top`. The two U-shaped slots
   beside each body magnet are door-stop clearances, not extra magnet holes.
   Dry-pair each door magnet with its matching body magnet and mark orientation
   before gluing: the exposed faces that meet when the door closes must
   **attract**. Use a small amount of compatible adhesive; the photos show
   medium CA glue. Seat each magnet flat in its recess, remove excess glue,
   and let it cure fully before mating the doors.

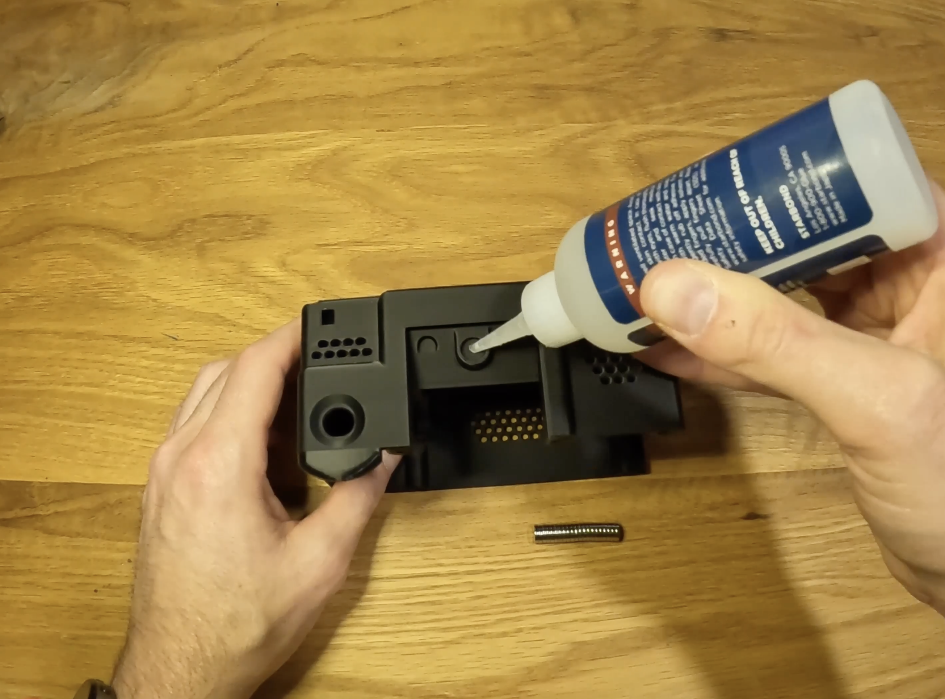
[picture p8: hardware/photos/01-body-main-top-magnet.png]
Photo 1: Applying adhesive at the body_main top-door magnet recess
   

   *Photo 1 — Top-door magnet location in `body_main`.*

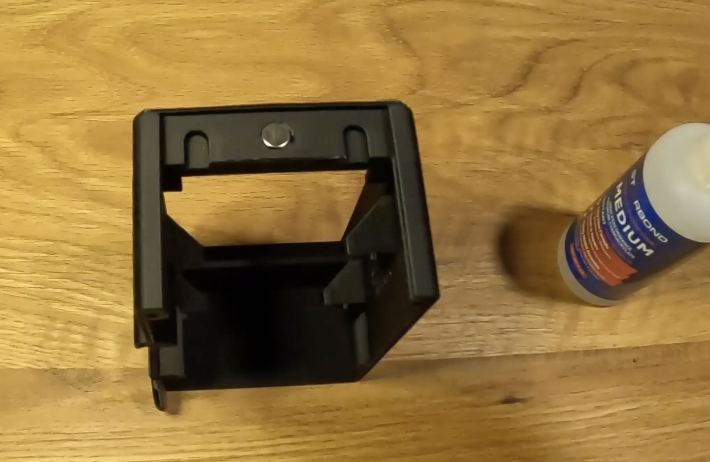
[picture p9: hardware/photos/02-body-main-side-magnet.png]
Photo 2: Single magnet at the body_main side-door opening between two clearance slots
   

   *Photo 2 — Side-door magnet in place, between the two door-stop clearances.*

4. Install **two M3×4 screws in each door**, four total. These act as stops behind
   `body_front` once assembled. Put one on either side of the magnet, with the
   round heads exposed on the door's inside face as shown below. Check that
   they catch the front cover while allowing the doors to slide; do not bury
   the heads or drive the screws through the door. Exact head dimensions and
   protrusion are still to be measured.

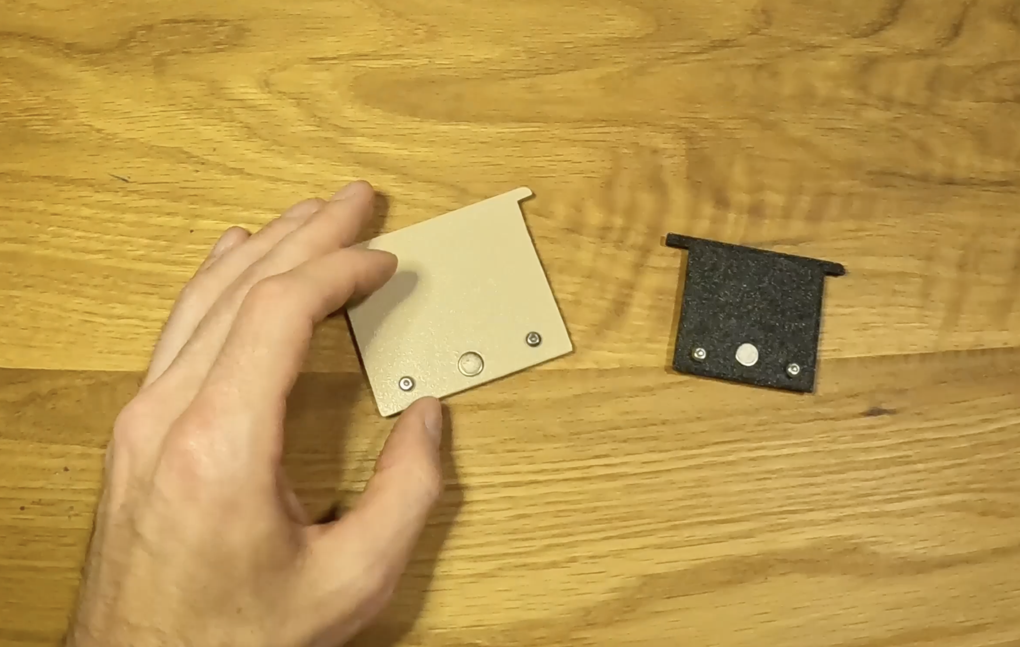
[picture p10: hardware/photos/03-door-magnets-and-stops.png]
Photo 3: Inside faces of the larger side door and smaller top door, each with one magnet location and two stop screws
   

   *Photo 3 — `door_side` on the left has its magnet recess visible;
   `door_top` on the right has its magnet installed. Each door has two stop screws.*

## 2. Mount the display, amplifier, and shutter

Keep PiSugar output off and all external power disconnected during assembly.
Work on a clean, nonconductive surface and protect the display face. Tighten
screws by hand until snug, without bowing boards or stripping printed holes.

5. Fit the display in `body_main`, with its screen facing out through the rear
   opening. Attach it using the **four M2.5 screws supplied with the display**.
   Check that it sits evenly and the board is not bowed.
6. Connect the included ribbon to the back of the display. Open the latch gently,
   insert the ribbon squarely with the correct contact orientation, and close
   the latch. Use the **DSI socket at the board's right edge in photo 4**; leave
   the factory panel ribbon at the centre of the board connected. Leave the
   Pi end of the DSI cable loose.

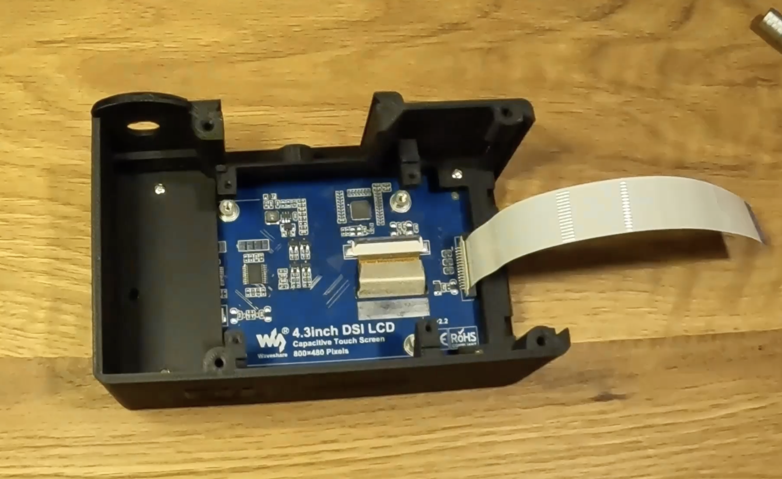
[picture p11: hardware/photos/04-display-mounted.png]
Photo 4: Waveshare display mounted in body_main, with its DSI cable leaving the right edge
   

   *Photo 4 — Display attached to `body_main`. The PCB is marked
   `4.3inch DSI LCD`, `800×480 Pixels`, and revision `2.2`.*

7. Attach the amplifier to its single mount in `body_main` with **one M3×6
   screw**. Keep the head clear of pads/components and prevent the board from
   rotating into another board.
8. With the Pi outside the housing, connect amplifier **VIN → pin 4; GND → pin
   6; BCLK → pin 12; LRC/LRCLK → pin 35; DIN → pin 40**. These are physical
   header numbers. Use the [wiring reference](WIRING.md#gpio-connections) to
   match terminal labels, and insulate any splices.
9. Insert the 10 mm switch's leads and threaded barrel through the shutter
   opening from outside. Secure it with the supplied nut inside `body_main`.
   Tighten without twisting the leads or distorting the housing, and check
   that the button moves and releases freely.
10. Connect its normally-open contacts to **physical pin 38 (GPIO20)** and
    **physical pin 39 (ground)**. The leads have no polarity. Pin 40 belongs to
    audio. A continuity check should show open when released and closed only
    while pressed.

## 3. Connect and mount the Pi and PiSugar

Prepare the microSD card with the OS, Wi-Fi, and SSH settings in
[DEVICE.md](../docs/DEVICE.md#prepare-raspberry-pi-os). Insert it before mounting
the Pi if access will be restricted. Install the application at first boot below.

11. Connect the display ribbon to the Pi's **DISPLAY / DSI** connector. Connect
    one end of the camera ribbon to the Pi's **CAMERA / CSI** connector; leave
    the camera end loose until assembling the lens mount. Check latches and contact orientation
    using the [connector references](WIRING.md#camera-display-and-battery).

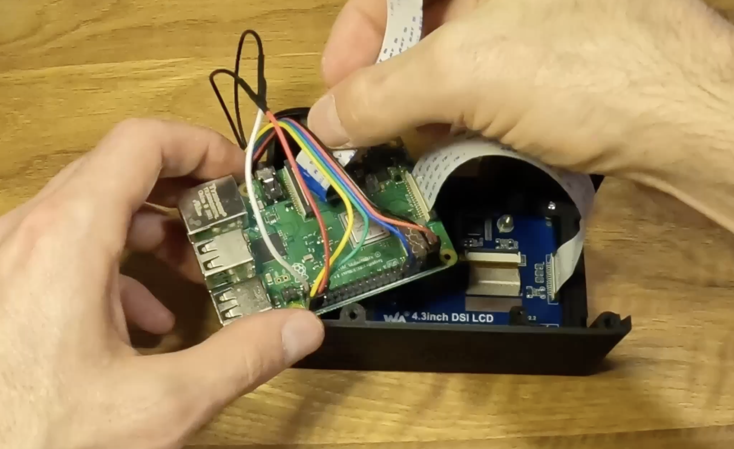
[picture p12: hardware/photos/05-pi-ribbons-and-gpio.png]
Photo 5: Pi held component side up with GPIO leads and both ribbon cables attached before mounting
    

    *Photo 5 — Connect the GPIO leads and ribbons while the Pi is accessible.
    It is shown component side up here and is flipped over in the next step.
    Use the [numbered pin table](WIRING.md#gpio-connections) for wiring; some
    header connections are hidden in this photo.*

12. Set the Pi into `body_main` with its **component side facing down toward
    the back of the display**, aligning all four mounting holes. Keep every
    cable clear of the screw posts and the gap between the Pi and its mounts.
    Check that Pi components do not press against the display PCB.
13. Place PiSugar against the **underside of the Pi**, aligning its spring
    contacts with the GPIO solder pads and its four holes with the Pi's holes.
    Follow [PiSugar mounting preparation](https://docs.pisugar.com/docs/product-wiki/battery/pisugar3/pisugar-3-series),
    removing protective film from its mounting nuts if present. Hold the boards
    together at their mounting areas, avoiding pressure on the battery pouch.
14. While holding PiSugar in place, pass the **four supplied M2.5 screws**
    through PiSugar and Pi mounting holes into `body_main`, as specified for
    this enclosure. Start all four, then gently tighten diagonally. Check that
    the boards stay parallel and the spring contacts seat firmly. The battery
    faces the open front of the housing as shown in photo 6. Exact M2.5 screw
    lengths and board spacing still need measurement: stop if a screw bottoms out,
    fails to engage, bows a board, or approaches the battery. Do not force a
    longer screw into place.

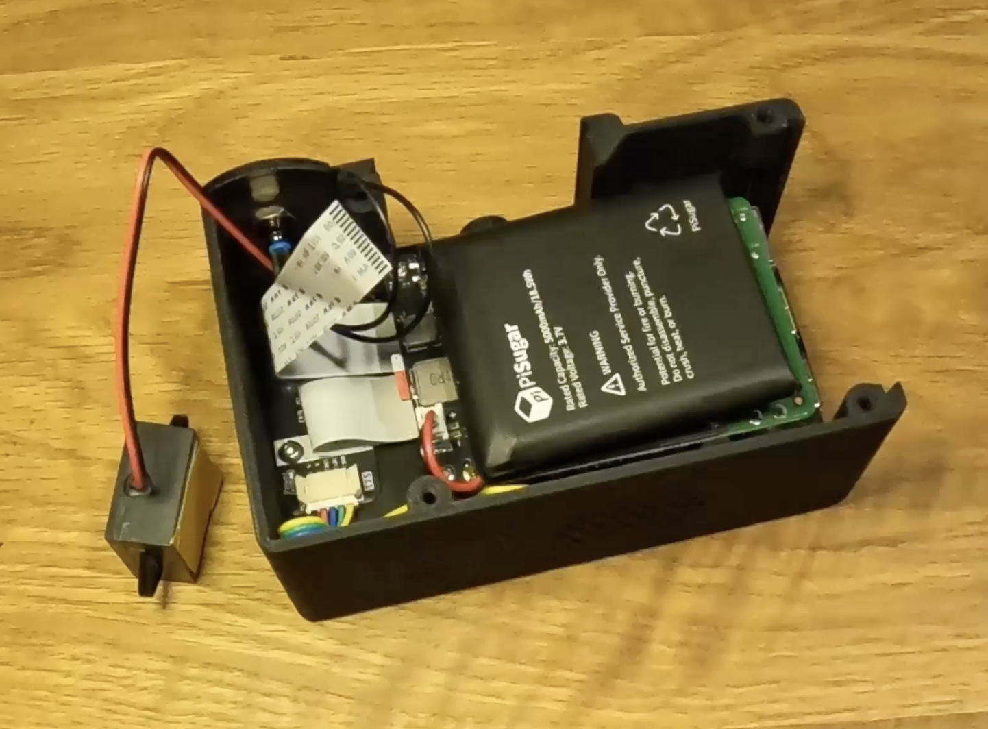
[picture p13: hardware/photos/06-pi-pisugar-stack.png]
Photo 6: Pi and PiSugar installed above the display, with the battery facing the open front and amplifier beside the stack
    

    *Photo 6 — From the display toward the open front: Pi component side,
    Pi underside, PiSugar, then battery. Keep ribbons and leads clear of the
    mounting posts. The amplifier sits beside the stack.*

15. Slide both doors into their matching positions. Check magnetic attraction
    and free movement. Their stop screws are captured by the front cover later,
    so support the doors while handling the open body.

## 4. Assemble the camera mount

16. Set Camera Module 3 onto the locating pins on `lens_back`, aligning the PCB
    holes and ribbon connector with the mount. Handle it by its board edges.
    The lens must face through the opening in `lens_front`. If latch access is
    easier now, connect the camera end of the ribbon before seating the module,
    as in photo 7; keep the cable loose while assembling the mount.

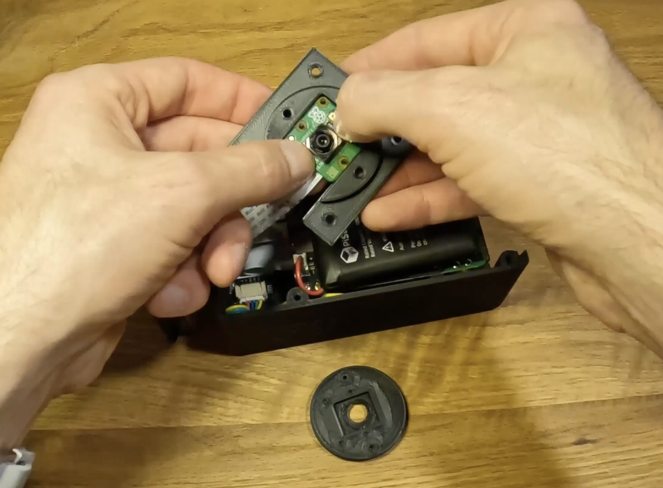
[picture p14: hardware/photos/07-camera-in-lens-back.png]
Photo 7: Camera Module 3 seated in lens_back, with the separate round lens_front below it
    

    *Photo 7 — Seat the camera in `lens_back`. The round `lens_front` lies below,
    with its inside face visible. The camera ribbon is already connected in
    this example.*

17. Place `lens_front` over the camera and `lens_back`, aligning the pins with
    its rear holes. The halves should sandwich the board without bending it or
    pressing on the lens actuator or ribbon connector.
18. Join the halves with **two M3×8 screws**, inserted from the rear of
    `lens_back` into `lens_front`. Use the two inner holes beside the camera
    cutout; reserve the four outer flange holes for mounting to `body_front`.
    Tighten evenly, just enough to retain the camera. Remove print debris and
    any removable lens protector. Check clearance around the moving lens;
    do not use screws to pull a binding mount together.

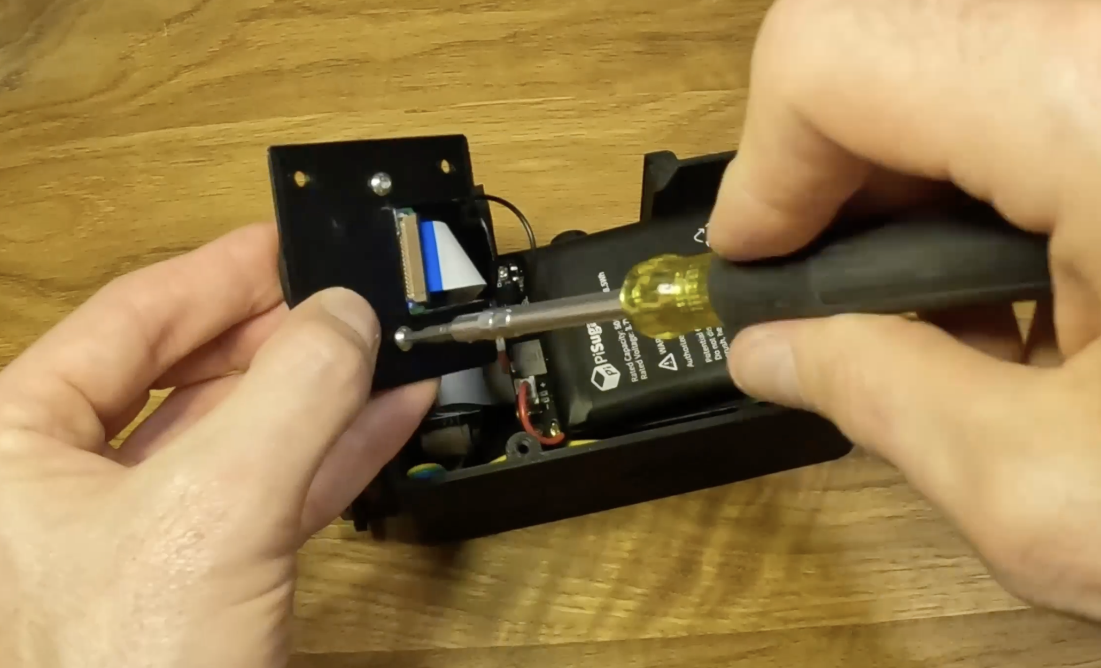
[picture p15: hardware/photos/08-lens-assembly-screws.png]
Photo 8: Two screws driven from the back of lens_back into lens_front, with camera cable accessible through the cutout
    

    *Photo 8 — The two inner M3×8 screws hold the lens halves together.
    The ribbon connector remains accessible through the rear cutout.*

19. If not already connected, attach the ribbon from the Pi to Camera Module 3.
    Check contact orientation, seat it squarely, and close the latch. Leave a gentle service
    loop so moving the front cover will not tug on the socket.

## 5. Prepare the front cover

20. Fit the lens assembly into `body_front`, with `lens_front` projecting
    through the opening and the `lens_back` flange on the inside. Align the
    four mounts and leave the ribbon exit clear, as in photo 9.
21. Attach the lens assembly to `body_front` with **four M3×6 screws** through
    the outer flange holes, working from inside the front cover. Tighten evenly
    without stressing the camera board. These are separate from the two inner
    screws that hold the lens halves together.

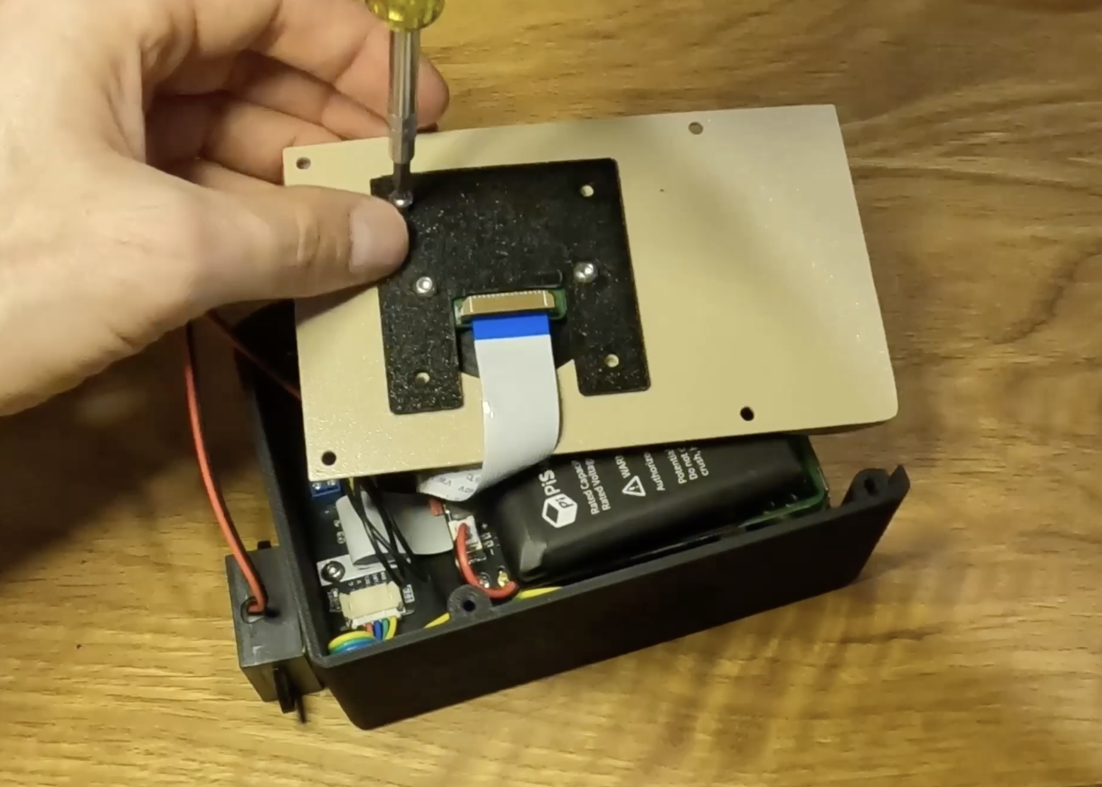
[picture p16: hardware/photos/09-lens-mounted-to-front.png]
Photo 9: Lens_back flange attached to the inside of body_front through its four outer mounting holes
    

    *Photo 9 — Inside face of `body_front`: the lens flange sits against the
    panel, and the camera ribbon exits through its open notch. The four holes
    near the panel edges are for attaching the complete front cover later.*

22. Attach the speaker's flat back to the inside of `body_front`, beside the
    lens mount, using double-sided tape. The **speaker cone faces into the
    housing**, as in photo 10. Keep tape off the cone and sound openings;
    the speaker's mounting tabs do not need screws in this build. Connect
    its leads to the amplifier's speaker output; neither lead goes to Pi ground.
    Support the front cover beside the body so cables carry no weight.

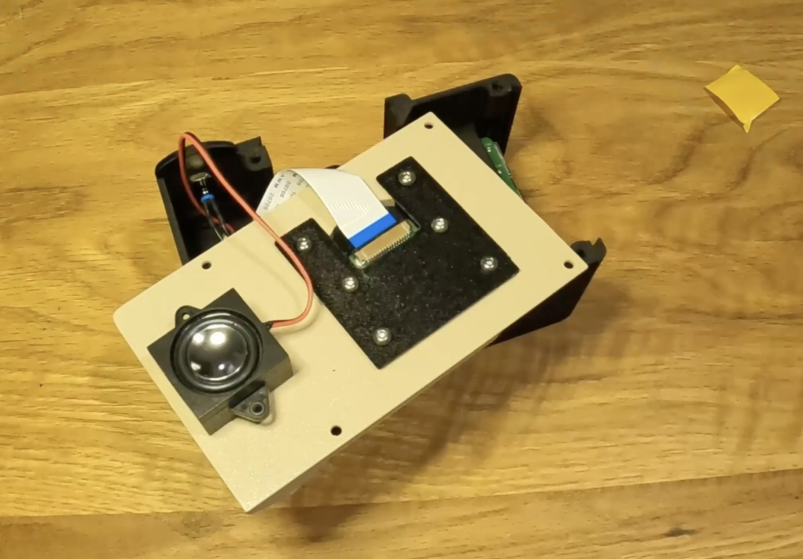
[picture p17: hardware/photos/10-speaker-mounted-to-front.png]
Photo 10: Speaker taped beside the lens assembly on the inside of body_front, with its cone facing the camera interior
    

    *Photo 10 — Completed inside face of the front cover, with the speaker
    beside the lens assembly and both cables free to route into `body_main`.*

## 6. Install the software and test before closing

Inspect for loose metal, exposed connections, misplaced GPIO leads, trapped
cables, and screws touching the battery or components. Then turn on PiSugar.
Keep the front cover supported and accessible for the first test; power off
again before changing any connection.

Follow [DEVICE.md](../docs/DEVICE.md) for OS setup and device registration.
For **this camera**, install with:

```bash
curl -fsSL https://raw.githubusercontent.com/danny-hines/muse-cam/main/scripts/install-device.sh \
  | sudo bash -s -- --profile pi3bplus-cam3-dsi43 --claim YOUR-SETUP-CODE
```

The installer may reboot when hardware configuration changes. Then complete:

- **Battery:** follow [POWER.md](../docs/POWER.md#pisugar-3-plus-setup) to install
  PiSugar Power Manager, enable I²C, and set `MUSECAM_POWER_BACKEND=pisugar3` in
  `/etc/musecam/device.env`. Select **PiSugar 3** in the manager, including for
  Plus boards. Battery reporting alone does not configure safe shutdown.
- **Audio:** follow [amplifier setup](../docs/DEVICE.md#amplifier-and-speaker-bring-up)
  to compile and enable `musecam-i2s-output` followed by `max98357a,no-sdmode`.
  This manual step keeps GPIO20 free for the shutter.

After the required reboot, run diagnostics:

```bash
sudo systemctl stop musecam
sudo -u musecam /opt/muse-cam/.venv/bin/musecam \
  --config /etc/musecam/device.env doctor
sudo systemctl start musecam musecam-kiosk
```

Check before fitting the front cover:

- Preview is upright, unobstructed, and focused at near and far distances.
  Inspect an original photo, not just an AI result. **Camera Module 3 autofocus
  remains unresolved in the existing prototype test record**; see
  [camera results](../docs/CAMERAS.md#camera-module-3-initial-hardware-results--2026-09-12).
  Resolve binding or persistent blur before closing the camera.
- Touch controls work, and each shutter press produces one capture. Try at least
  ten captures, including a few close together.
- Settings → Sounds plays clean cues at low volume.
- Battery percentage appears after PiSugar setup, and the camera runs on battery
  with the charger removed.
- A capture, processing, and gallery-viewing cycle succeeds over Wi-Fi. Test
  sharing only with an image intended for the public roll.

## 7. Close the camera and check the finished build

23. Shut down the Pi cleanly, wait for it to halt, and turn off PiSugar output.
    Place `body_front` over `body_main`. Keep cables away from the seam, door
    tracks, and screw posts. Both stop screws on each door must sit behind the
    front cover.
24. Attach `body_front` using the final **four M3×6 screws**. Tighten evenly
    without forcing the seam closed. Check that doors remain retained, the
    shutter moves freely, and charging/service openings are accessible. Slide
    `door_side` toward the camera front to expose the Pi's USB and Ethernet
    ports, as in photo 14. Check that its stop screws limit travel and keep
    it captured, then close it so the magnets meet.

Power up and repeat preview, focus, touch, shutter, speaker, and battery checks
with the enclosure closed. Confirm a normal shutdown/restart and charging through
the PiSugar port. Run long enough to observe heat and battery runtime; record
actual test duration, temperature, and results before claiming expected runtime
or thermal performance for the enclosure.

### Completed camera

These finished builds show the exterior in cream/black and orange/white.
Use them to compare the front-cover fit, lens opening, display surround,
shutter position, and side-door movement. Wrist straps shown here are optional.

Photo 11: Completed cream-and-black Muse Cam viewed from the front, showing all four front-cover screws and the closed side door

*Photo 11 — Front cover fastened at its four corners, with the lens centred in
the opening and the side door closed.*

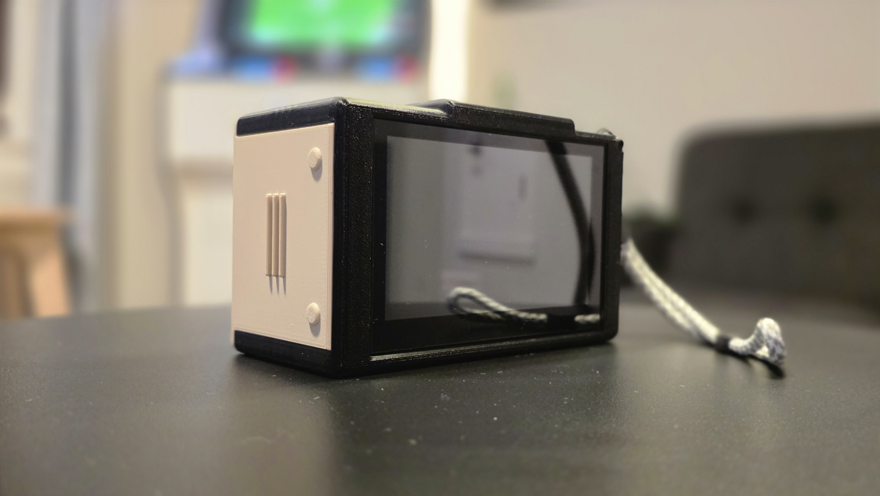
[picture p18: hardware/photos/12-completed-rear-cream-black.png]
Photo 12: Rear view of the cream-and-black camera showing the touchscreen, closed side door, and wrist strap


*Photo 12 — Rear touchscreen and closed side door. The strap is an optional
accessory; it is not part of the six printed pieces.*

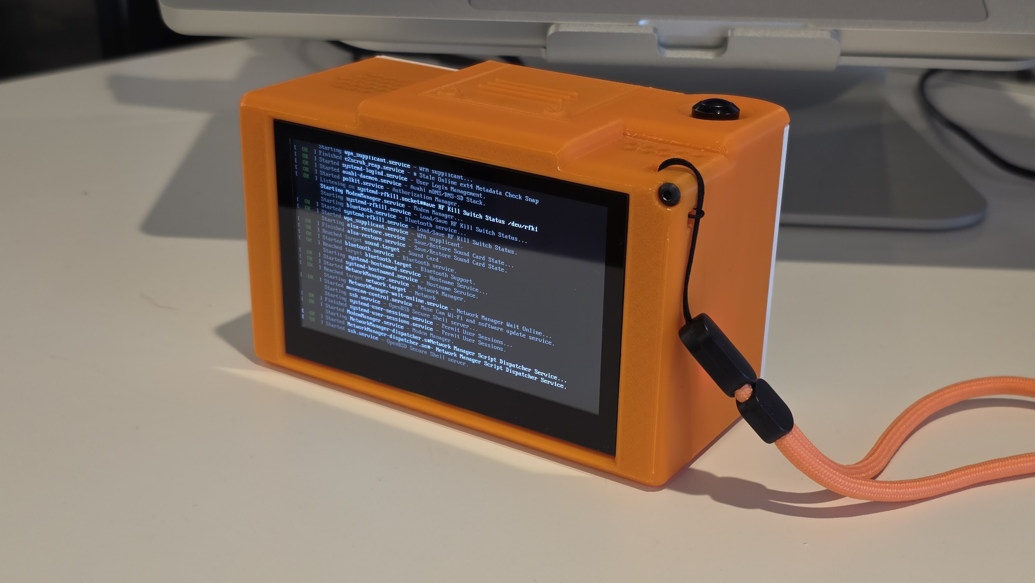
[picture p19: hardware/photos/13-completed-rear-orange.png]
Photo 13: Orange-and-white camera viewed from the rear and above, showing the top door, shutter button, wrist strap, and boot text on the display


*Photo 13 — Top door, shutter, and rear display on the orange build. The screen
shows the operating system booting.*

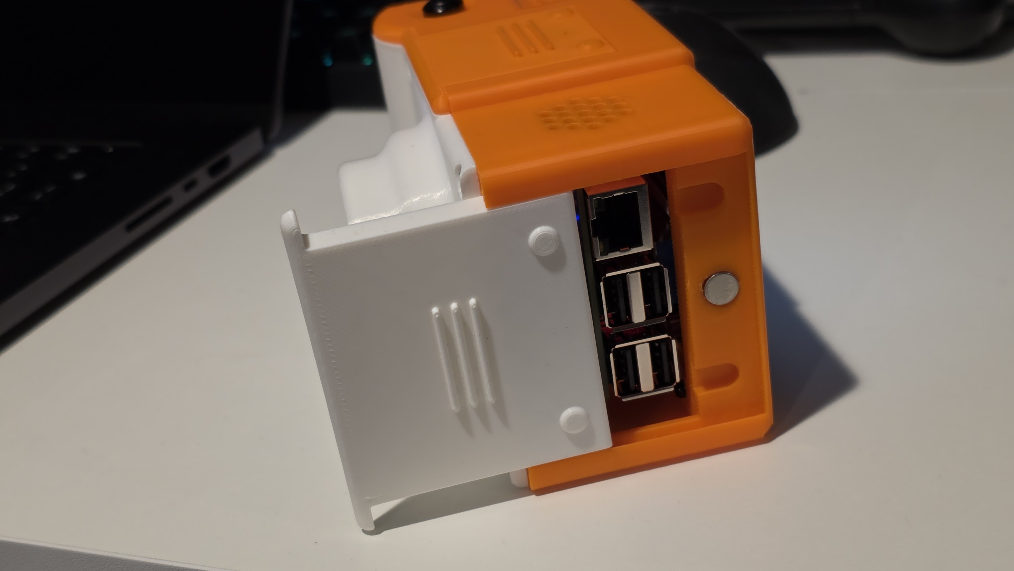
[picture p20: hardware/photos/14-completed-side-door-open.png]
Photo 14: Side door slid toward the camera front to expose the Raspberry Pi Ethernet and USB ports, with the body magnet visible


*Photo 14 — Side access door open: Ethernet at the top and the stacked USB ports
below it in this view. The body magnet is visible beside the ports.*

## Remaining measurements and checks

Photos 1–10 document magnet locations, door stops, the display and Pi/PiSugar
arrangement, the lens sandwich and flange, and speaker placement. Photos 11–14
show the completed exterior and side-port access. The following details still
need measurements or functional checks:

| Needed | What it resolves |
| --- | --- |
| Printed parts on the print bed, plus slicer settings | Material, orientation, supports, nozzle, layer height, walls, infill, and scale |
| Door-stop screws and their installed height measured | Exact head dimensions, thread form, and protrusion |
| Ribbons laid out with a ruler; unobstructed views of connector contacts | Cable lengths and contact orientation at each end |
| Amplifier connector labels and speaker rear label | Harness lead order, speaker impedance and dimensions |
| Pi/PiSugar stack from the side; supplied screws beside a ruler | M2.5 lengths and board spacing |
| Near/far focus test with the camera in its printed mount | Lens movement, clearance, and focus performance |
| Door travel and access to power/charging controls tested on the assembled unit | Both doors remain captured and controls/charging connector can be reached; side USB/Ethernet access is shown in photo 14 |

Editable CAD, the final mechanical revision name, and a completed physical build
using the recorded print settings are still pending.

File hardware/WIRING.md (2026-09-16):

# Muse Cam wiring

For Raspberry Pi 3B+, Camera Module 3, Waveshare 4.3-inch DSI, PiSugar 3 Plus,
and a MAX98357A amplifier. Connect everything with external power removed and
PiSugar output off. Unplugging USB alone does not remove battery power.

## GPIO connections

**Physical pin numbers** identify positions on the Pi's 40-pin header.
**BCM GPIO numbers** are the signal names used by software. For example, GPIO20
is physical pin 38. Identify pin 1 using the Pi's marking/square pad and the
[Raspberry Pi header reference](https://www.raspberrypi.com/documentation/computers/raspberry-pi.html#gpio).
Numbering stays the same when the Pi is installed upside down; an underside view
is mirrored. Attach and label the leads before installing the Pi.

| Component terminal | Pi physical pin | Pi signal | Purpose |
| --- | ---: | --- | --- |
| Amplifier VIN / VCC | **4** | 5 V | Amplifier power |
| Amplifier GND | **6** | Ground | Common ground |
| Amplifier BCLK / BCK | **12** | BCM GPIO18 / PCM_CLK | I²S bit clock |
| Amplifier LRC / LRCLK / WS | **35** | BCM GPIO19 / PCM_FS | I²S left/right clock |
| Amplifier DIN | **40** | BCM GPIO21 / PCM_DOUT | Audio data from Pi to amplifier |
| Shutter lead 1 | **38** | BCM GPIO20 | Shutter input |
| Shutter lead 2 | **39** | Ground | Shutter return |

The amplifier signal mapping follows
[Adafruit's Raspberry Pi wiring guide](https://learn.adafruit.com/adafruit-max98357-i2s-class-d-mono-amp/raspberry-pi-wiring).
Pins 4 and 6 are the power/ground positions selected for this guide; wire by the
board's terminal labels, not an assumed color or connector order.
[Photo 5](photos/05-pi-ribbons-and-gpio.png) shows the connected Pi before it is
flipped into the housing, but some header pins are obscured. The amplifier
harness is visible in [photo 6](photos/06-pi-pisugar-stack.png); a readable
close-up of its terminal labels is still needed to document connector order.

Connect the speaker's leads to amplifier **SPK+ and SPK−** (or its supplied
speaker connector). Neither speaker terminal goes to Pi ground: the output is
bridged. Keep 5 V on VIN/VCC only, away from GPIO signal inputs. Additional SD/EN
or GAIN pins on a different breakout need that board's documentation; the
five-wire build uses no GPIO shutdown/enable lead.
[Amplifier pin reference](https://learn.adafruit.com/adafruit-max98357-i2s-class-d-mono-amp/pinouts).

## Shutter behavior

Use the normally-open switch contacts. The leads have no polarity. Pressing the
button connects **pin 38 to pin 39**; released, the contacts are open. Muse Cam
enables an internal pull-up and debounces the switch, so no external pull-up
resistor is needed. Do not add a connection to 5 V or 3.3 V.

**Do not connect the shutter between pins 39 and 40.** Pin 40 is amplifier DIN.
The DSI profile intentionally has no separate GPIO power button. See
[the Camera Module 3 profile](../device/profiles/pi3bplus-cam3-dsi43.toml).

## Camera, display, and battery

| Component | Pi connection | Assembly note |
| --- | --- | --- |
| Camera Module 3 | 15-pin **CAMERA / CSI** socket | Insert Pi end before mounting Pi; connect camera end while its latch is accessible, either before seating the module as in photo 7 or after joining the lens halves. |
| Waveshare display | 15-pin **DISPLAY / DSI** socket | Connect display end first, then Pi end before mounting Pi. |
| PiSugar 3 Plus | Spring contacts against **underside** of Pi GPIO solder pads | Supplies power and I²C through mounting interface; no separate telemetry leads. |

Open each ribbon latch gently, insert the cable squarely with exposed contacts
facing the socket contacts, and close both sides evenly. Confirm orientation at
each socket using the [camera instructions](https://www.raspberrypi.com/documentation/accessories/camera.html)
and [display instructions](https://www.waveshare.com/wiki/4.3inch_DSI_LCD).
The cable's blue stiffener is not a universal orientation rule. See
[photo 4](photos/04-display-mounted.png) for the display's right-edge DSI socket,
[photo 5](photos/05-pi-ribbons-and-gpio.png) for Pi cable routing, and
[photo 8](photos/08-lens-assembly-screws.png) for camera connector access through
`lens_back`. The display's central factory panel ribbon stays connected.
Contact faces are not visible at every connector; verify each against its socket.

PiSugar mounts on the Pi's underside even though the Pi's component side faces
the display inside this enclosure. Keep its contact area unobstructed. Its I²C
uses BCM GPIO2/3 (physical pins 3/5), separate from amplifier I²S signals.
See [PiSugar mounting instructions](https://docs.pisugar.com/docs/product-wiki/battery/pisugar3/pisugar-3-series)
and [Muse Cam battery setup](../docs/POWER.md).

## Required software selections

1. Install with **`pi3bplus-cam3-dsi43`**; see [the build guide](BUILD.md#6-install-the-software-and-test-before-closing).
2. Configure PiSugar Power Manager and set **`MUSECAM_POWER_BACKEND=pisugar3`**
   in `/etc/musecam/device.env` following [POWER.md](../docs/POWER.md). The
   camera profile still defaults to PiSugar S Plus; the override enables
   PiSugar 3 battery reporting.
3. Complete the manual [amplifier setup](../docs/DEVICE.md#amplifier-and-speaker-bring-up).
   Compile the supplied overlay before adding these boot configuration lines
   in this order, and reboot:

   ```ini
   dtoverlay=musecam-i2s-output
   dtoverlay=max98357a,no-sdmode
   ```

The ordinary Pi 3 I²S pin group also claims GPIO20 as audio input. Muse Cam's
[output-only overlay](../device/overlays/musecam-i2s-output.dts) preserves the
shutter on GPIO20. Audio setup is **not automatic** in the general installer;
follow the linked instructions in full, including compilation and disabling
onboard analog audio.

After reboot, `aplay -l` should list `MAX98357A`. While Muse Cam runs,
`pinctrl get 18-21` should show clock, frame-sync, shutter input, and audio output
respectively. Confirm one capture per shutter press and test the cues at low
volume in Settings → Sounds.

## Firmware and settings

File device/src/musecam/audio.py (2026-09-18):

from __future__ import annotations

import io
import json
import logging
import math
import os
import random
import select
import shutil
import struct
import subprocess
import sys
import threading
import wave
from collections import deque
from functools import lru_cache
from pathlib import Path

LOGGER = logging.getLogger(__name__)
CUES = {"shutter", "countdown", "processing", "success", "error"}
SAMPLE_RATE = 48000
CHUNK_FRAMES = 1024
SILENCE = bytes(CHUNK_FRAMES * 4)


def sound_wave(cue: str, volume: int) -> bytes:
    """Original, deterministic earcons; no downloaded audio or runtime dependencies."""
    if cue not in CUES:
        raise ValueError("Unknown sound")
    rate = SAMPLE_RATE
    duration = {
        "shutter": 0.19, "countdown": 0.12, "processing": 0.38, "success": 0.55, "error": 0.42
    }[cue]
    gain = 0.20 * (max(0, min(100, volume)) / 100) ** 2
    # The success melody carries much more strongly on the enclosure's speaker.
    if cue == "success":
        gain *= 0.5
    rng = random.Random(42)
    frames = bytearray()
    for i in range(round(duration * rate)):
        t = i / rate
        value = 0.0
        if cue == "shutter":
            # Two spring/curtain transients with a soft mechanical tail.
            for onset, weight in ((0.0, 1.0), (0.063, 0.75)):
                x = t - onset
                if x >= 0:
                    value += (
                        weight
                        * min(1, x / 0.0015)
                        * math.exp(-x * 95)
                        * (0.65 * rng.uniform(-1, 1) + 0.35 * math.sin(2 * math.pi * 1750 * x))
                    )
        elif cue == "countdown":
            value = 0.6 * math.sin(math.pi * t / duration) ** 2 * math.sin(2 * math.pi * 880 * t)
        elif cue == "processing":
            step = int(t / 0.062)
            x = t % 0.062
            if x < 0.035:
                frequency = (185, 250, 155, 215, 175, 280, 190)[step]
                value = (
                    0.13
                    * math.sin(math.pi * x / 0.035) ** 2
                    * math.sin(2 * math.pi * (frequency * x + 140 * x * x))
                )
        else:
            notes = (
                ((0.0, 660), (0.15, 880), (0.28, 1108))
                if cue == "success"
                else ((0.0, 330), (0.18, 247))
            )
            for onset, frequency in notes:
                x = t - onset
                if 0 <= x < 0.24:
                    envelope = min(1, x / 0.012, (0.24 - x) / 0.012) * math.exp(-x * 16)
                    value += 0.42 * envelope * math.sin(2 * math.pi * frequency * x)
        # Fade the final samples, avoiding a sharp cutoff.
        value *= min(1, max(0, (duration - t) / 0.015))
        sample = round(max(-1, min(1, value)) * gain * 32767)
        frames.extend(struct.pack("<hh", sample, sample))
    output = io.BytesIO()
    with wave.open(output, "wb") as wav:
        wav.setnchannels(2)
        wav.setsampwidth(2)
        wav.setframerate(rate)
        wav.writeframes(frames)
    return output.getvalue()


@lru_cache(maxsize=5)
def _samples(cue: str) -> tuple[int, ...]:
    with wave.open(io.BytesIO(sound_wave(cue, 100)), "rb") as wav:
        payload = wav.readframes(wav.getnframes())
    return struct.unpack(f"<{len(payload) // 2}h", payload)


class PcmMixer:
    """Fixed-size stereo PCM blocks, including silence while idle or muted."""

    def __init__(self) -> None:
        # Synthesize before opening ALSA: Python synthesis must not starve its buffer.
        self._clips = {cue: _samples(cue) for cue in CUES}
        self.cue: str | None = None
        self._position = 0
        self._gain = 0.0

    def start(self, cue: str) -> None:
        self.cue = cue
        self._position = 0
        self._gain = 0.0

    def render(self, volume: int, processing_enabled: bool) -> bytes:
        if self.cue is None:
            return SILENCE
        clip = self._clips[self.cue]
        cancelling = volume == 0 or (self.cue == "processing" and not processing_enabled)
        target = 0.0 if cancelling else (volume / 100) ** 2
        samples = clip[self._position : self._position + CHUNK_FRAMES * 2]
        count = len(samples)
        # Ramp changes over 5 ms; mute never cuts a nonzero sample abruptly.
        ramp_frames = SAMPLE_RATE // 200
        start_gain = self._gain
        output = [
            round(value * (start_gain + (target - start_gain) * min(1, (i // 2 + 1) / ramp_frames)))
            for i, value in enumerate(samples)
        ]
        self._gain = target
        self._position += count
        if cancelling or self._position >= len(clip):
            self.cue = None
            self._gain = 0.0
        return struct.pack(f"<{count}h", *output) + bytes(len(SILENCE) - count * 2)


def _device_available() -> bool:
    return bool(
        shutil.which("aplay")
        and Path("/proc/asound/cards").exists()
        and "MAX98357A" in Path("/proc/asound/cards").read_text()
    )


class _PcmStream:
    def __init__(self, *, simulate: bool, volume: int = 35) -> None:
        self.volume = volume
        self.processing_enabled = True
        self.available = not simulate and _device_available()
        self.error: str | None = None
        self._condition = threading.Condition()
        self._queue: deque[str] = deque(maxlen=4)
        self._closed = False
        self._process: subprocess.Popen | None = None
        self._mixer: PcmMixer | None = None
        self._thread = threading.Thread(target=self._run, name="musecam-audio", daemon=True)
        self._thread.start()

    def configure(self, volume: int, processing_enabled: bool) -> None:
        with self._condition:
            self.volume = volume
            self.processing_enabled = processing_enabled
            if volume == 0:
                self._queue.clear()
            # Keep the PCM stream alive even when muted: stopping I2S clocks pops.
            self._condition.notify()

    def play(self, cue: str) -> None:
        if cue not in CUES:
            raise ValueError("Unknown sound")
        with self._condition:
            if not self.available or not self.volume or self._closed:
                return
            if cue == "processing":
                if (
                    not self.processing_enabled
                    or self._queue
                    or (self._mixer is not None and self._mixer.cue is not None)
                ):
                    return
            else:
                self._queue = deque(
                    (item for item in self._queue if item != "processing"), maxlen=4
                )
            self._queue.append(cue)
            self._condition.notify()

    def _run(self) -> None:
        if not self.available:
            return
        process = None
        try:
            mixer = PcmMixer()
            with self._condition:
                if self._closed:
                    return
                self._mixer = mixer
                # One fixed-rate raw stream for the application's lifetime. A small
                # pipe bounds queued silence so the shutter remains responsive.
                process = subprocess.Popen(
                    [
                        "aplay",
                        "-q",
                        "-D",
                        "plughw:CARD=MAX98357A,DEV=0",
                        "-t",
                        "raw",
                        "-f",
                        "S16_LE",
                        "-r",
                        str(SAMPLE_RATE),
                        "-c",
                        "2",
                        "--period-size=1024",
                        "--buffer-size=4096",
                        "--fatal-errors",
                    ],
                    stdin=subprocess.PIPE,
                    stdout=subprocess.DEVNULL,
                    stderr=subprocess.PIPE,
                    bufsize=0,
                    pipesize=4096,
                )
                self._process = process
            # Establish clocks with silence before any queued cue.
            warmup_blocks = 12
            while True:
                with self._condition:
                    if self._closed:
                        break
                    if warmup_blocks:
                        payload = SILENCE
                        warmup_blocks -= 1
                    else:
                        if mixer.cue is None and self._queue and self.volume:
                            mixer.start(self._queue.popleft())
                        payload = mixer.render(self.volume, self.processing_enabled)
                if process.poll() is not None:
                    raise OSError("Audio stream exited")
                # ALSA / pipe backpressure provides pacing; never spin or sleep a
                # Python timer that can drift and interrupt the hardware clocks.
                remaining = memoryview(payload)
                while remaining:
                    written = process.stdin.write(remaining)
                    if not written:
                        raise OSError("Audio stream disconnected")
                    remaining = remaining[written:]
        except (OSError, subprocess.SubprocessError):
            if not self._closed:
                self.error = "Speaker stream stopped. Restart the camera to restore sounds."
                self.available = False
                # Do not reopen in a loop: that would produce repeated loud pops.
                LOGGER.warning("Speaker stream failed", exc_info=True)
        finally:
            if process is not None:
                if process.poll() is None:
                    process.terminate()
                try:
                    process.wait(timeout=2)
                except subprocess.TimeoutExpired:
                    process.kill()
                    process.wait()
                if process.stdin is not None:
                    process.stdin.close()
                if process.stderr is not None:
                    if not self._closed:
                        detail = process.stderr.read(2000).decode(errors="replace").strip()
                        if detail:
                            LOGGER.warning("Speaker stream: %s", detail)
                    process.stderr.close()
            with self._condition:
                self._process = None

    def close(self) -> None:
        with self._condition:
            self._closed = True
            if self._process is not None and self._process.poll() is None:
                self._process.terminate()
        self._thread.join(timeout=4)


class SoundPlayer(_PcmStream):
    """Control audio in a separate interpreter, isolated from camera GIL stalls."""

    def _run(self) -> None:
        if not self.available:
            return
        process = None
        try:
            with self._condition:
                if self._closed:
                    return
                process = subprocess.Popen(
                    [sys.executable, "-m", "musecam.audio", "--worker"],
                    stdin=subprocess.PIPE,
                    stdout=subprocess.DEVNULL,
                    stderr=subprocess.PIPE,
                    text=True,
                    bufsize=1,
                )
                self._process = process
            configured = None
            while True:
                with self._condition:
                    if self._closed:
                        break
                    if process.poll() is not None:
                        raise OSError("Audio worker exited")
                    settings = (self.volume, self.processing_enabled)
                    commands = []
                    if settings != configured:
                        commands.append({"volume": settings[0], "processing": settings[1]})
                        configured = settings
                    while self._queue:
                        commands.append({"cue": self._queue.popleft()})
                    if not commands:
                        self._condition.wait(timeout=0.25)
                        continue
                for command in commands:
                    process.stdin.write(json.dumps(command) + "\n")
                process.stdin.flush()
        except (OSError, subprocess.SubprocessError):
            if not self._closed:
                self.error = "Speaker stream stopped. Restart the camera to restore sounds."
                self.available = False
                LOGGER.warning("Speaker worker failed", exc_info=True)
        finally:
            if process is not None:
                # EOF lets the worker close ALSA and reap aplay before exiting.
                try:
                    process.stdin.close()
                except OSError:
                    pass
                try:
                    process.wait(timeout=2)
                except subprocess.TimeoutExpired:
                    process.terminate()
                    try:
                        process.wait(timeout=2)
                    except subprocess.TimeoutExpired:
                        process.kill()
                        process.wait()
                if process.stderr is not None:
                    detail = process.stderr.read(2000).strip()
                    if detail and not self._closed:
                        LOGGER.warning("Speaker worker: %s", detail)
                    process.stderr.close()
            with self._condition:
                self._process = None

    def close(self) -> None:
        with self._condition:
            self._closed = True
            self._condition.notify()
        self._thread.join(timeout=5)


def _worker() -> int:
    """Tiny line-based command channel; PCM never shares the camera interpreter."""
    player = _PcmStream(simulate=False, volume=0)
    pending = b""
    try:
        while player.available:
            readable, _, _ = select.select([sys.stdin], [], [], 0.1)
            if not readable:
                continue
            data = os.read(sys.stdin.fileno(), 4096)
            if not data:
                return 0
            pending += data
            while b"\n" in pending:
                line, pending = pending.split(b"\n", 1)
                command = json.loads(line)
                if "cue" in command:
                    player.play(command["cue"])
                else:
                    player.configure(command["volume"], command["processing"])
        return 1
    finally:
        player.close()


if __name__ == "__main__" and sys.argv[1:] == ["--worker"]:
    raise SystemExit(_worker())

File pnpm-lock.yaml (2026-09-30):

lockfileVersion: '9.0'

settings:
  autoInstallPeers: true
  excludeLinksFromLockfile: false

importers:

  .: {}

  device-ui:
    dependencies:
      react:
        specifier: 19.2.8
        version: 19.2.8
      react-dom:
        specifier: 19.2.8
        version: 19.2.8(react@19.2.8)
    devDependencies:
      '@types/react':
        specifier: 19.2.18
        version: 19.2.18
      '@types/react-dom':
        specifier: 19.2.5
        version: 19.2.5(@types/react@19.2.18)
      '@vitejs/plugin-react':
        specifier: 6.1.1
        version: 6.1.1(vite@8.2.2(@types/node@26.4.0)(esbuild@0.28.2)(tsx@4.23.13))
      typescript:
        specifier: 5.9.3
        version: 5.9.3
      vite:
        specifier: 8.2.2
        version: 8.2.2(@types/node@26.4.0)(esbuild@0.28.2)(tsx@4.23.13)

  web:
    dependencies:
      '@neondatabase/serverless':
        specifier: 1.1.0
        version: 1.1.0
      '@vercel/blob':
        specifier: 2.8.0
        version: 2.8.0
      drizzle-orm:
        specifier: 0.45.2
        version: 0.45.2(@electric-sql/pglite@0.5.8)(@neondatabase/serverless@1.1.0)
      next:
        specifier: 16.3.4
        version: 16.3.4(@babel/core@7.29.7(supports-color@7.2.0))(@types/node@26.4.0)(react-dom@19.2.8(react@19.2.8))(react@19.2.8)
      qrcode:
        specifier: 1.5.4
        version: 1.5.4
      react:
        specifier: 19.2.8
        version: 19.2.8
      react-dom:
        specifier: 19.2.8
        version: 19.2.8(react@19.2.8)
      sharp:
        specifier: 0.35.4
        version: 0.35.4(@types/node@26.4.0)
      three:
        specifier: 0.186.1
        version: 0.186.1
      zod:
        specifier: 4.5.4
        version: 4.5.4
    devDependencies:
      '@electric-sql/pglite':
        specifier: ^0.5.8
        version: 0.5.8
      '@types/node':
        specifier: 26.4.0
        version: 26.4.0
      '@types/qrcode':
        specifier: 1.5.6
        version: 1.5.6
      '@types/react':
        specifier: 19.2.18
        version: 19.2.18
      '@types/react-dom':
        specifier: 19.2.5
        version: 19.2.5(@types/react@19.2.18)
      '@types/three':
        specifier: 0.186.0
        version: 0.186.0
      dotenv-cli:
        specifier: 11.0.0
        version: 11.0.0
      drizzle-kit:
        specifier: 0.31.10
        version: 0.31.10
      eslint:
        specifier: 9.39.5
        version: 9.39.5(supports-color@7.2.0)
      eslint-config-next:
        specifier: 16.3.4
        version: 16.3.4(@typescript-eslint/parser@8.68.0(eslint@9.39.5(supports-color@7.2.0))(supports-color@7.2.0)(typescript@5.9.3))(eslint@9.39.5(supports-color@7.2.0))(supports-color@7.2.0)(typescript@5.9.3)
      meshoptimizer:
        specifier: 1.3.0
        version: 1.3.0
      typescript:
        specifier: 5.9.3
        version: 5.9.3
      vitest:
        specifier: 4.1.11
        version: 4.1.11(@types/node@26.4.0)(vite@8.2.2(@types/node@26.4.0)(esbuild@0.28.2)(tsx@4.23.13))

packages:

  '@babel/code-frame@7.29.7':
    resolution: {integrity: sha512-Aup7aUOfpbAUg2ROOJN6Iw5f9DMBlzu0mIkm/malLQFN/YQgO48wCj0Kxa3sEHJvPVFg7siR+qRInwXd2qhQKw==}
    engines: {node: '>=6.9.0'}

  '@babel/compat-data@7.29.7':
    resolution: {integrity: sha512-locTkQyKvwIEgBzVrn8693ebc97F2U8ZHjbXwDXJ5Fn2TCpNwTlKcaKLkdHop5c/icOFE7qt7Q9JC5hnKNa6Gg==}
    engines: {node: '>=6.9.0'}

  '@babel/core@7.29.7':
    resolution: {integrity: sha512-RgHBCvtjbOK2gXSNBNIkNoEc9qoVEtau3hj8gEqKQuL3HZAibKarWFEI3Lfm6EYKkLalOh8eSrj9b+ch9H/VBA==}
    engines: {node: '>=6.9.0'}

  '@babel/generator@7.29.8':
    resolution: {integrity: sha512-gZbepsdh3WDtgZKWL+vTPh71LSBrm/Y4/QDZBVCcYfmeTEEuoOYwlSy+G1StfJg+/Zy550u/3TATbm7qDbbMtg==}
    engines: {node: '>=6.9.0'}

  '@babel/helper-compilation-targets@7.29.7':
    resolution: {integrity: sha512-wem6WaBj4NaVYVdNhLPPVacES6ZJ+KBBfSkTMD3YZxbP3rm3Di85tJU5ljaUNhaOynt+Aj0xruhYuzQBt8n71g==}
    engines: {node: '>=6.9.0'}

  '@babel/helper-globals@7.29.7':
    resolution: {integrity: sha512-3nQVUAtvkKH9zahfWgw96Jc/uFOmjACE1kQz82E2lqWmHBgjzbNlsC22nuQTfahmWeQtTq5nQ/4Nnd2A1wj4zA==}
    engines: {node: '>=6.9.0'}

  '@babel/helper-module-imports@7.29.7':
    resolution: {integrity: sha512-ejHwrQQYcm9xnTivShn2IDOlIzInN34AXskvq9QicvCtEzq1Vzclu/tKF8Jq1Cg8JG2GL6/EmjgsCT7lXepE3g==}
    engines: {node: '>=6.9.0'}

  '@babel/helper-module-transforms@7.29.7':
    resolution: {integrity: sha512-UPUVSyXbOh627KiCIGQSgwWzGeBKLkaJ9PJEdrngIwMSzxLR4jS4+f1f1jb7VzBbg8nFLaYotvVPFCTqdrmTAg==}
    engines: {node: '>=6.9.0'}
    peerDependencies:
      '@babel/core': ^7.0.0

  '@babel/helper-string-parser@7.29.7':
    resolution: {integrity: sha512-Pb5ijPrZ89GDH8223L4UP8i6QApWxs04RbPQJTeWDV0/keR2E36MeKnyr6LYmUUvqRRI+Iv87SuF1W6ErINzYw==}
    engines: {node: '>=6.9.0'}

  '@babel/helper-validator-identifier@7.29.7':
    resolution: {integrity: sha512-qehxGkRj55h/ff8EMaJ+cYhyaKlHIxqYDn682wQD7RNp9UujOQsHog2uS0r2vzr4pW+sXf90NeeayjcNaX3fFg==}
    engines: {node: '>=6.9.0'}
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

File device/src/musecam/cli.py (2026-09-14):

from __future__ import annotations

import argparse
import json
import logging
import os
import time
from dataclasses import asdict
from pathlib import Path
from typing import Any

from .app import MuseCamApp
from .client import MuseCamClient
from .config import DEFAULT_CONFIG_PATH, load_config, load_profile
from .diagnostics import run_diagnostics


def build_parser() -> argparse.ArgumentParser:
    parser = argparse.ArgumentParser(prog="musecam")
    parser.add_argument("--config", type=Path, default=DEFAULT_CONFIG_PATH)
    subcommands = parser.add_subparsers(dest="command", required=True)
    subcommands.add_parser("health", help="Check the deployed API")
    subcommands.add_parser("presets", help="List available style presets")

    claim = subcommands.add_parser("claim", help="Register this camera with a setup code")
    claim.add_argument("code")
    claim.add_argument("--name", help="Camera name (otherwise uses the admin suggestion)")
    claim.add_argument("--server", help="Registration server URL")

    submit = subcommands.add_parser("submit", help="Submit an existing image")
    submit.add_argument("image", type=Path)
    submit.add_argument("--preset", default="alien-visitor")
    submit.add_argument("--capture-id")
    submit.add_argument("--output", type=Path, default=Path("musecam-result.jpg"))
    submit.add_argument("--share", action="store_true")

    run = subcommands.add_parser("run", help="Start the full-screen camera application")
    run.add_argument("--profile", help="Override MUSECAM_PROFILE")
    run.add_argument("--simulate", action="store_true", help="Use a desktop test camera and window")
    run.add_argument("--windowed", action="store_true", help="Do not use full-screen display mode")
    run.add_argument("--offline", action="store_true", help="Use local presets and skip API calls")
    run.add_argument("--frames", type=int, help=argparse.SUPPRESS)
    run.add_argument("--screenshot", type=Path, help=argparse.SUPPRESS)
    run.add_argument("--capture-on-start", action="store_true", help=argparse.SUPPRESS)

    serve = subcommands.add_parser("serve", help="Start the local browser camera application")
    serve.add_argument("--profile", help="Override MUSECAM_PROFILE")
    serve.add_argument("--simulate", action="store_true", help="Use the desktop test camera")
    serve.add_argument(
        "--offline", action="store_true", help="Use local presets and skip API calls"
    )
    serve.add_argument("--host", default="127.0.0.1")
    serve.add_argument("--port", type=int, default=8080)

    doctor = subcommands.add_parser("doctor", help="Check camera, display, GPIO, storage, and API")
    doctor.add_argument("--profile", help="Override MUSECAM_PROFILE")
    doctor.add_argument("--json", action="store_true")
    return parser


def _json_value(value: Any) -> Any:
    if hasattr(value, "__dataclass_fields__"):
        return asdict(value)
    if isinstance(value, Path):
        return str(value)
    raise TypeError(f"Cannot serialize {type(value).__name__}")


def _print_json(value: Any) -> None:
    print(json.dumps(value, indent=2, default=_json_value))


def _run_api_command(args: argparse.Namespace) -> int:
    client = MuseCamClient(load_config(args.config))
    try:
        if args.command == "health":
            result: Any = client.health()
        elif args.command == "presets":
            result = {"presets": client.presets()}
        else:
            capture_id = args.capture_id or f"cli_{int(time.time())}"
            generation = client.generate(args.image, capture_id, args.preset)
            result = asdict(generation)
            if generation.image_url:
                client.download_result(generation.image_url, args.output)
                result["downloadedTo"] = str(args.output)
            if args.share:
                generation = client.share(generation.id)
                result = asdict(generation)
        _print_json(result)
        return 0
    finally:
        client.close()


def _update_env_file(path: Path, values: dict[str, str]) -> None:
    existing: list[str] = path.read_text(encoding="utf-8").splitlines() if path.exists() else []
    remaining = dict(values)
    output: list[str] = []
    for line in existing:
        if "=" not in line or line.lstrip().startswith("#"):
            output.append(line)
            continue
        key = line.split("=", 1)[0].strip()
        if key in remaining:
            output.append(f"{key}={remaining.pop(key)}")
        else:
            output.append(line)
    output.extend(f"{key}={value}" for key, value in remaining.items())
    path.parent.mkdir(parents=True, exist_ok=True)
    temporary = path.with_suffix(f"{path.suffix}.tmp")
    temporary.write_text("\n".join(output) + "\n", encoding="utf-8")
    os.chmod(temporary, 0o640)
    temporary.replace(path)


def _run_claim(args: argparse.Namespace) -> int:
    import httpx

    existing = load_config(args.config, require_credentials=False)
    server_url = (args.server or (existing.server_url if args.config.exists() else None))
    server_url = (server_url or "https://www.muse-cam.com").rstrip("/")
    payload = {"code": args.code}
    if args.name:
        payload["name"] = args.name
    response = httpx.post(f"{server_url}/api/device/claim", json=payload, timeout=20)
    if not response.is_success:
        try:
            message = response.json().get("error", "Registration failed")
        except (ValueError, AttributeError):
            message = "Registration failed"
        raise RuntimeError(f"{message} ({response.status_code})")
    registration = response.json()
    _update_env_file(
        args.config,
        {
            "MUSECAM_SERVER_URL": str(registration["serverUrl"]).rstrip("/"),
            "MUSECAM_DEVICE_TOKEN": str(registration["token"]),
            "MUSECAM_DEVICE_ID": str(registration["deviceId"]),
        },
    )
    print(f"Registered {registration['deviceName']} ({registration['deviceId']})")
    print("Restart musecam.service to use the new credential.")
    return 0


def _run_app(args: argparse.Namespace) -> int:
    config = load_config(args.config, require_credentials=not args.offline)
    profile = load_profile(
        args.profile or config.profile_id, config.profiles_dir, power_backend=config.power_backend
    )
    logging.basicConfig(
        level=getattr(logging, config.log_level, logging.INFO),
        format="%(asctime)s %(levelname)s %(name)s: %(message)s",
    )
    app = MuseCamApp(
        config,
        profile,
        simulate=args.simulate,
        windowed=args.windowed,
        offline=args.offline,
    )
    app.run(
        max_frames=args.frames,
        screenshot=args.screenshot,
        capture_on_start=args.capture_on_start,
    )
    return 0
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

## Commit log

2026-09-01 Initial Muse Cam web and device scaffold
2026-09-01 Build Raspberry Pi camera application
2026-09-02 Allow service account to read device config
2026-09-02 Keep device UI active without camera
2026-09-02 Handle idle touch input on Raspberry Pi OS
2026-09-02 Calibrate Pi 3 touchscreen orientation
2026-09-02 Correct direct touchscreen vertical mapping
    [test_config.py]
2026-09-02 Correct touchscreen horizontal mapping
    [test_config.py]
2026-09-02 Tune Pi 3 camera preview
2026-09-02 Handle filtered generations gracefully
2026-09-02 Match Pi 3 preview rate to SPI throughput
2026-09-02 Reduce SPI preview traffic
2026-09-02 Try balanced SPI preview timing
2026-09-02 Add browser camera and fleet operations
2026-09-04 Clean up display overlays when switching profiles
2026-09-08 Reduce preview load on enclosed cameras and clarify photo failures
    [system.py, test_webapp.py, webapp.py]
2026-09-08 Clarify retry guidance and private camera update setup
2026-09-08 Fix update file permissions and close preview streams on shutdown
    [test_system_control.py, test_webapp.py, webapp.py]
2026-09-08 Keep amplifier playback continuous and isolate audio from camera work
2026-09-08 Balance success melody against the other camera cues
2026-09-08 Clarify scene presets and document content filtering results
2026-09-08 Keep camera buffers allocated and recover stalled capture streams
    [camera.py, test_camera.py, test_webapp.py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]
2026-09-09 Promote Smooth+Wide to Insert Disc 2 and retire test variants
2026-09-09 Add IMX519 and Camera Module 3 autofocus profiles and swap setup
    [boot_config.py, camera.py, config.py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]
2026-09-09 Add tap-to-focus with confirmed focus state and automatic area reset
    [camera.py, test_camera.py, test_webapp.py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]
2026-09-14 Support PiSugar battery swaps independently of camera profiles
    [cli.py, config.py, test_config.py]
2026-09-14 Improve preview cadence and reduce kiosk graphics memory pressure
2026-09-16 Add illustrated Muse Cam hardware build guide and STL files
    Document the parts list, GPIO wiring, 24 assembly steps, and manual audio and PiSugar setup. Include six original STL exports with dimensions and checksums, ten assembly photos, and four completed-ca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
    [body_front.stl, body_main.stl, door_side.stl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]
2026-09-16 Remove enclosure concept renders and documentation
2026-09-17 Add event controls and synchronize camera photo sharing
2026-09-17 Include legacy cameras in the managed device registry
2026-09-18 Add event galleries for shared camera photos
2026-09-18 Add random styles, photo swiping, and a camera shutter timer
2026-09-18 Return to camera before capturing from gallery
2026-09-21 Fix camera claim registration with Neon HTTP
    [pnpm-lock.yaml]
2026-09-24 Add twelve camera styles including pirate and Western themes
2026-09-26 Allow operators to rename registered cameras
2026-09-27 Add a spinning 3D model of the camera to the home page
2026-09-27 Show the 3D camera on event pages
2026-09-28 Caption shared photos with Muse Spark
    After a photo is published, Muse Spark writes a short "caption this"
    style joke about the restyled image. It runs after the share response,
    so the camera API and its responses are unchanged. Captions appear on
    gallery cards, photo pages, and link previews, and operators can write
    or replace one from /admin.
2026-09-28 Give Found in 1997 a late-90s makeover
    Version 1 only changed the photographic treatment, so results often
    looked like a modern photo with a flash. Version 2 keeps the disposable
    camera look and adds everyday period clothes, 1990s hair, and period
    equivalents for modern devices and furnishings, with at most two added
    props and buildings left as photographed. The camera loads styles from
    the server, so this needs no camera update.
2026-09-30 Let events choose camera styles and add Meta event styles
    Each event can now pick the styles its cameras show, including event-only
    styles that never appear in the default catalog. The presets endpoint reads
    the credential cameras already send, so existing cameras get their event's
    list after a restart, with no update. Events without a choice keep the
    default catalog, and the server refuses event-only styles from cameras at
    other events.
    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
2026-09-30 Work through every surprise style before repeating one
    Surprise photos picked each style independently, so a camera often
    repeated a style within a few shots: four photos from 14 styles repeat
    one about a third of the time. Each camera now gets the event's styles
    in a random order, preferring ones it hasn't used recently, and only
    repeats once it has used them all. Filter fallbacks follow the same
    order.
2026-09-30 Stop the kiosk preview freezing and hide the picker for one style
    Debian's Chromium adds --disable-dev-shm-usage whenever /dev/shm has less
    than 3.8 GB free, which is always true on a Pi, so Chromium kept shared
    memory, including every preview frame, in /tmp on the SD card. That was
    about 38 MB/s of card writes and a 1-2 second preview freeze every few
    seconds. The kiosk now points TMPDIR at /dev/shm, which dropped card
    writes to near zero on a Pi 3B+.
    When the server sends a single style, as at a Surprise event, the camera
    skips its own Random entry, hides the style picker, and restyles gallery
    photos without asking for a style.
    [test_webapp.py, webapp.py]
2026-09-30 Label surprise photos on the camera with the style the server used
    Cameras labeled every Surprise photo "Surprise" because they kept the
    style they asked for. The generation response now includes the style's
    name, and cameras save the style ID and name the server used, adding a
    style-name column to their local database. Photos from before the
    update keep their old label.
